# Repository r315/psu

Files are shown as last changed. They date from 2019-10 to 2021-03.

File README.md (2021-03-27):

# DPSU

Desk power supply project is intended to develop a compact desk power supply with a dummy load. The power supply can be used to power small devices and perform simple battery capacity test.

---
## Specs

### Power supply

Output: 1.3V - 20V
Output Current: 0A - 1A
Voltage adjustment steps: 100mV
Current adjustment steps: 10mA

### Battery charger

Max charge current: 1A
Battery types: 1S to 4S Li-ion

### Dummy load

Max load: 0.5A
Battery capacity test

---
## Features

* 0.96" Color TFT Screen
* Frontal USB port type A for usb power output
* 1S to 4S Li-ion battery balancer
* Optional supply voltage from internal battery
* Soft power control
* USB serial port available on rear micro usb port type B
* Digital control from tactile keys or serial

---
## Schematics

[Power board](/doc/dpsu_revA_Power_board.PDF)<br>
[Main board](/doc/dpsu_revA_Main_board.PDF)<br>
[Front board](/doc/dpsu_revA_Front_board.PDF)<br>

---
## Images

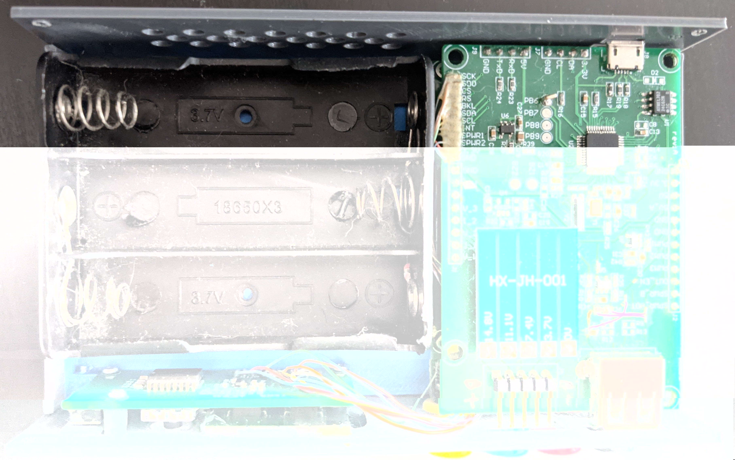
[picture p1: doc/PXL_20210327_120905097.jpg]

<div><br></div>
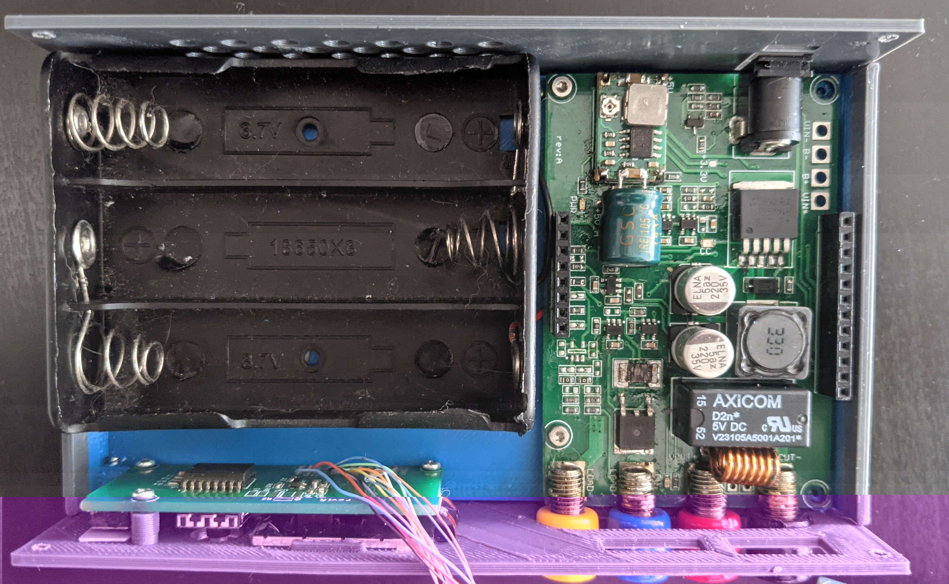
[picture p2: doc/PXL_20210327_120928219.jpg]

<div><br></div>
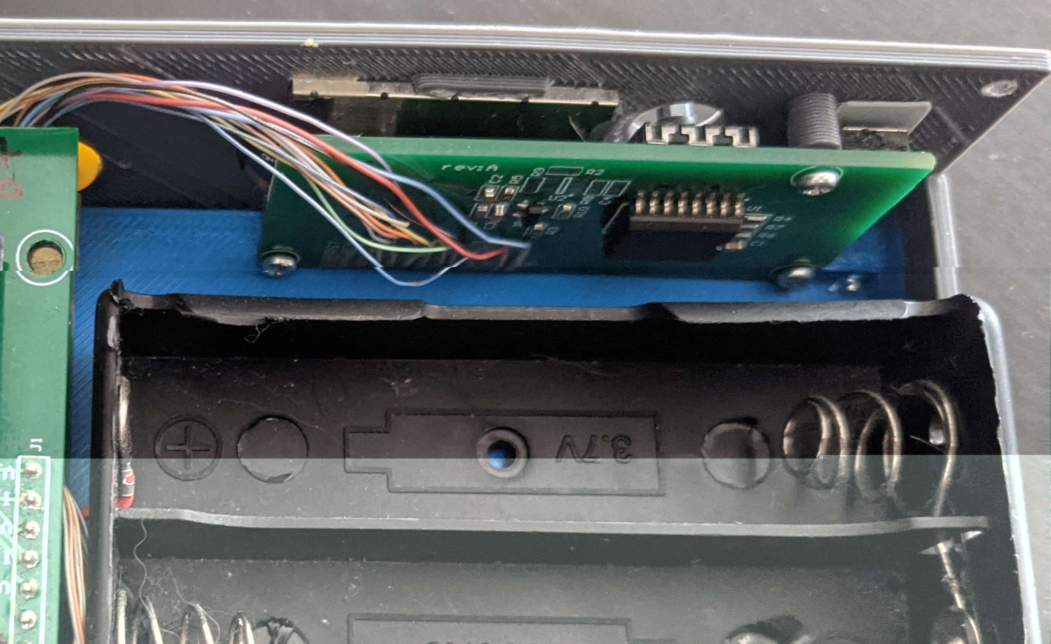
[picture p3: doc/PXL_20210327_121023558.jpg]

<div><br></div>

<div><br></div>
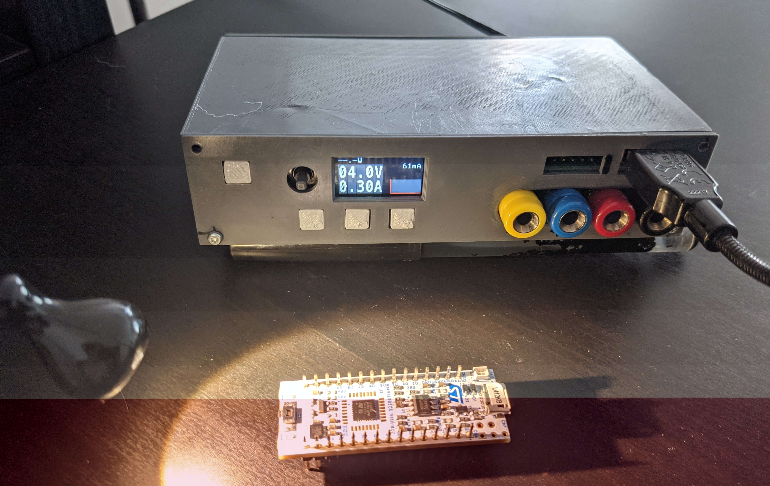
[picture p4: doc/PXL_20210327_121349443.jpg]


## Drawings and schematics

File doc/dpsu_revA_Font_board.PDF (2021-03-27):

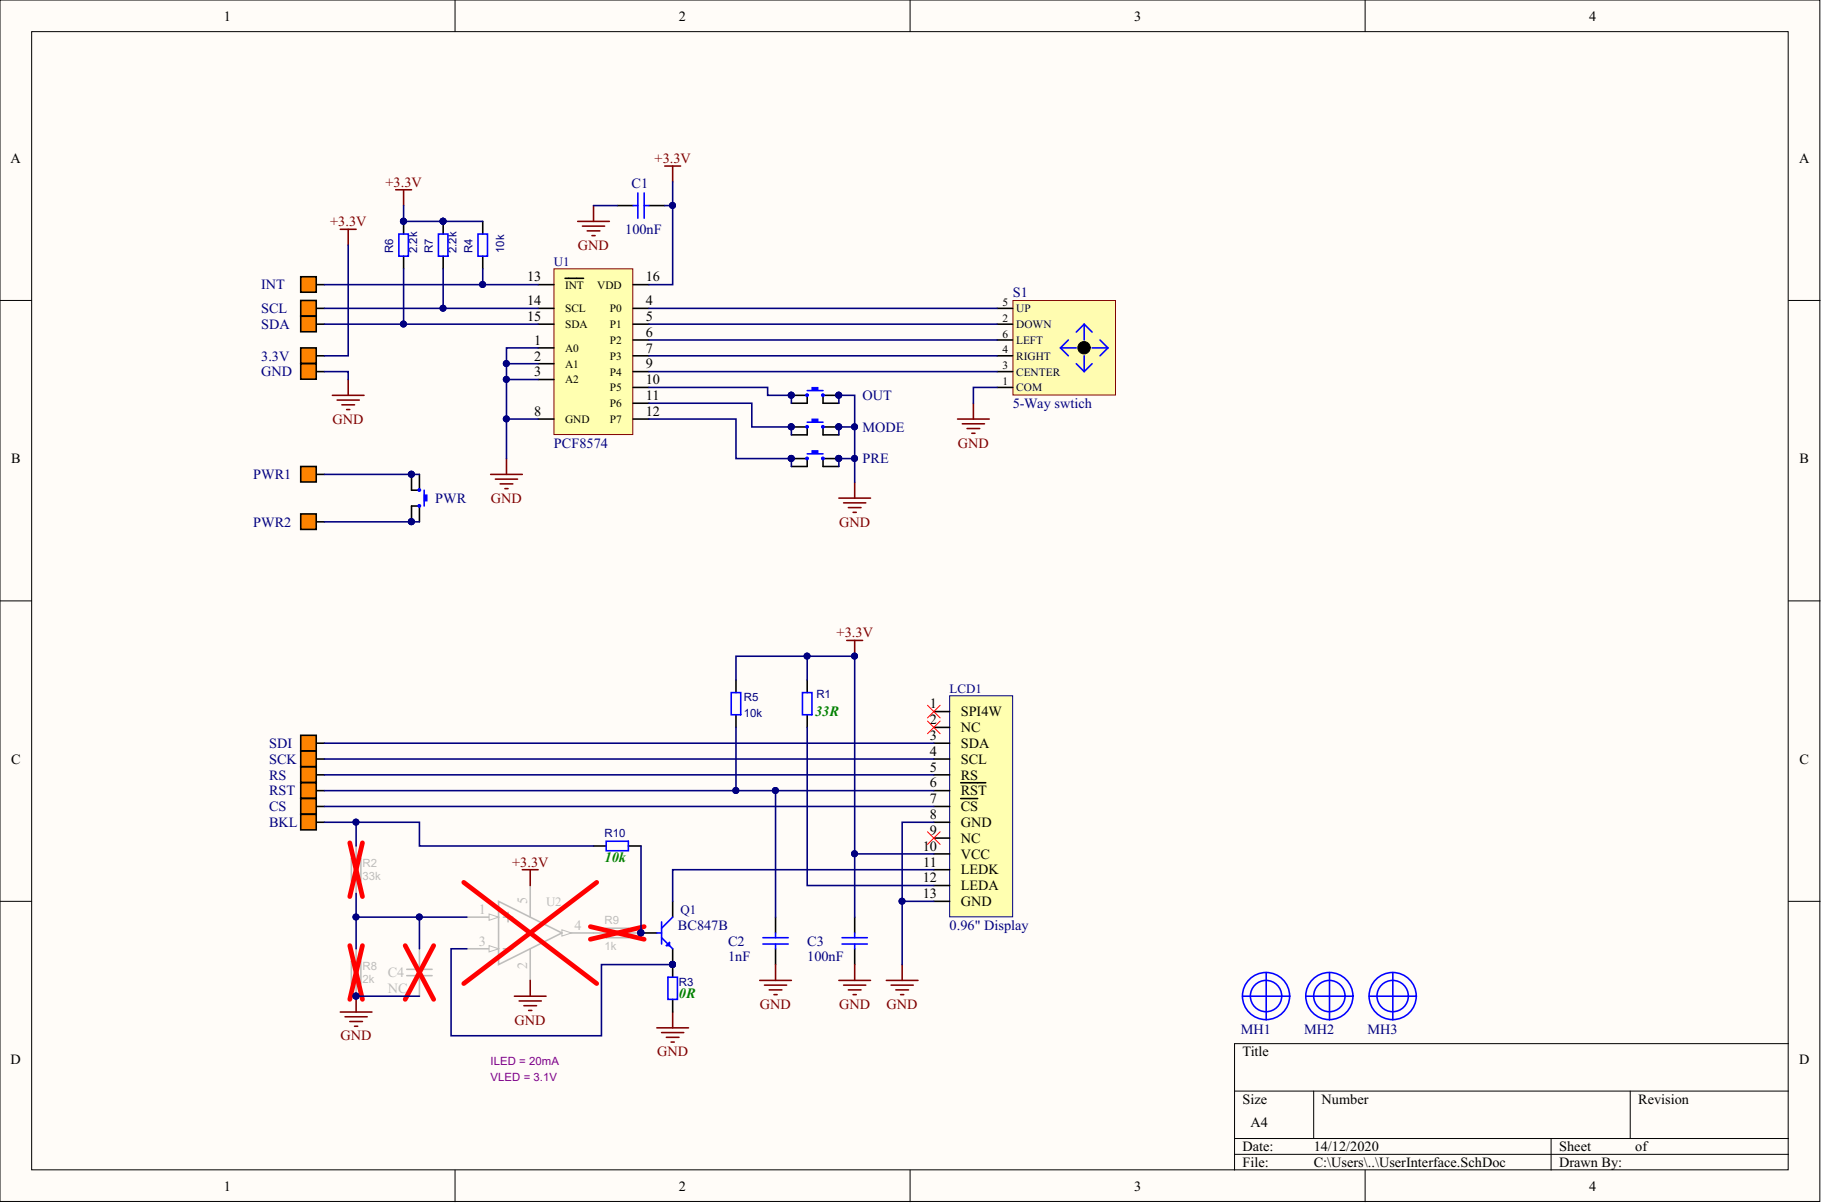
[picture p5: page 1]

SDA 3
SCL 4
RS 5
RST 6
CS 7
GND 8
NC 9

LEDK 11

GND 13

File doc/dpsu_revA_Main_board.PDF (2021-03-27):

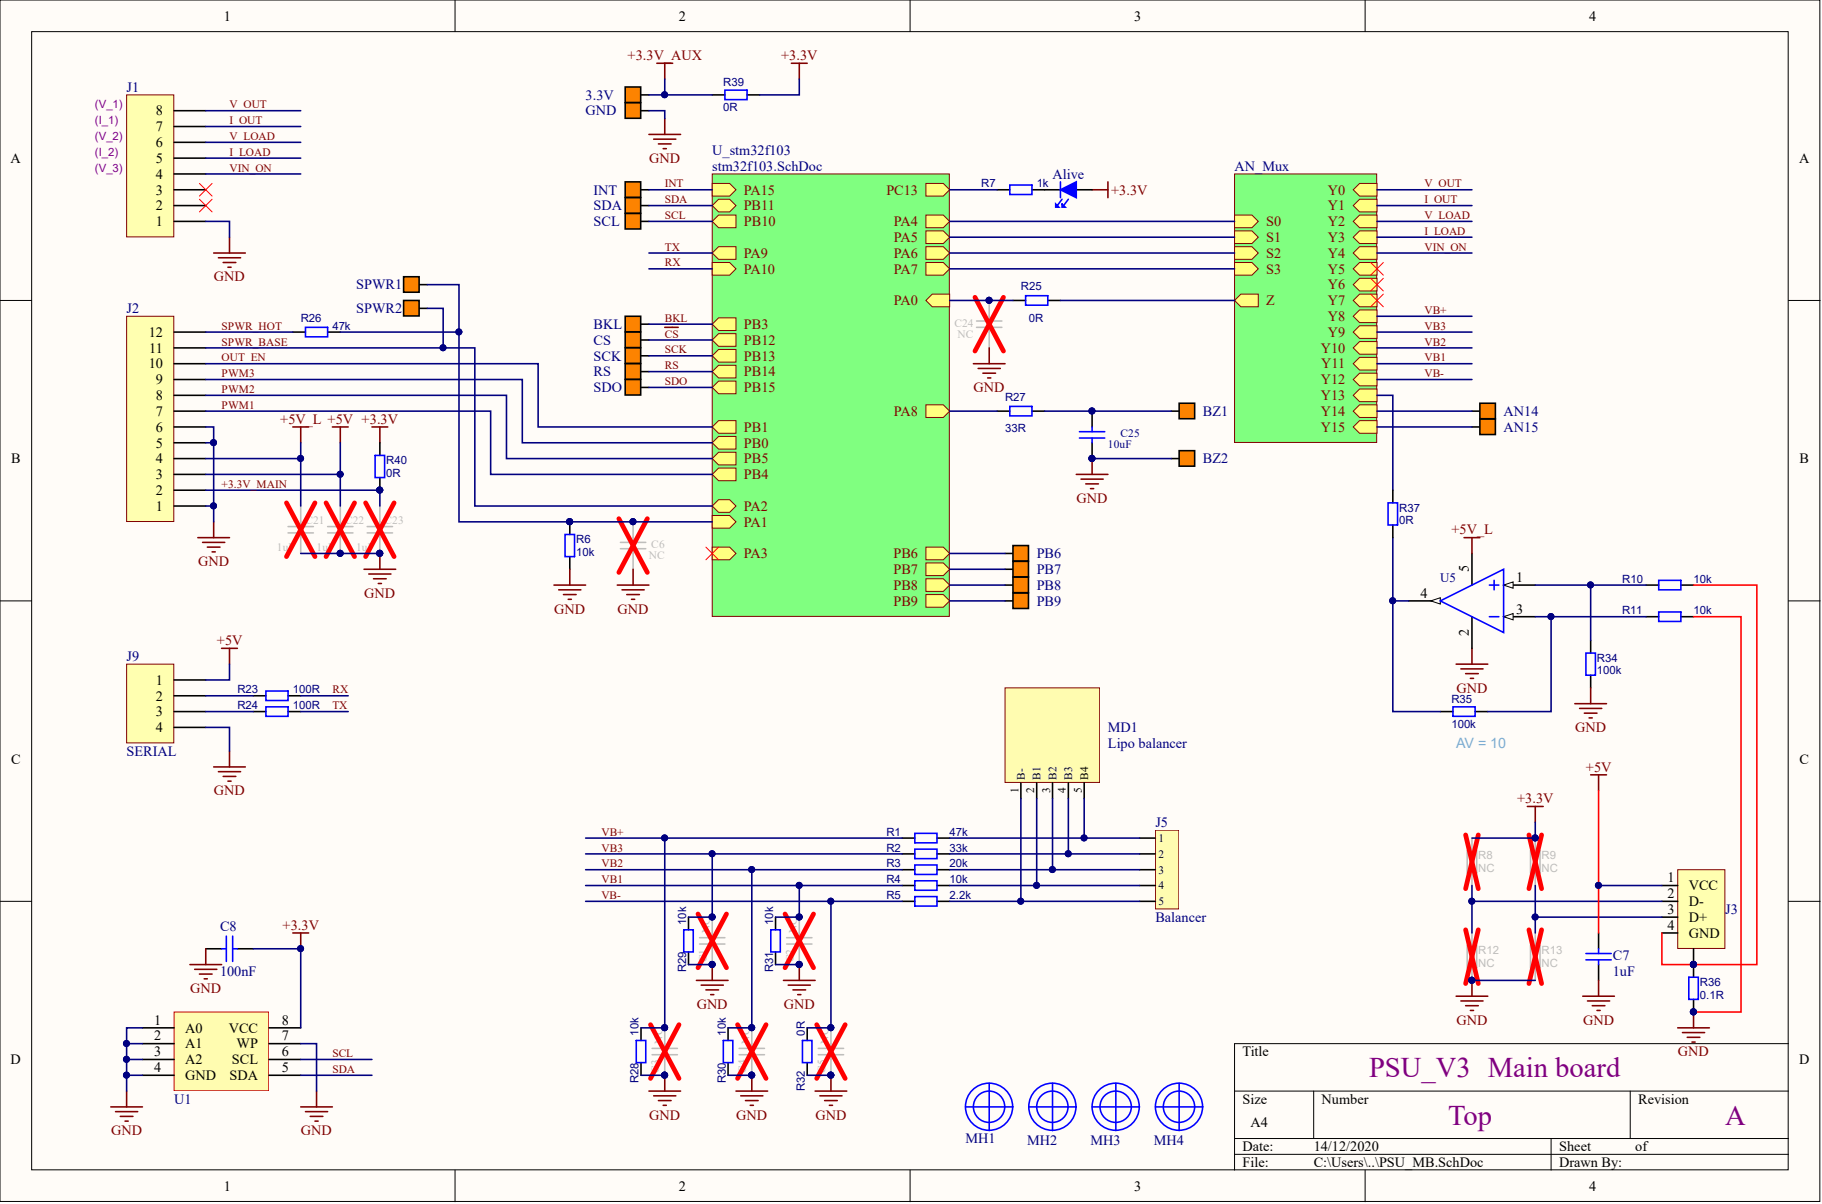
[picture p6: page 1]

OUT_EN | SCK | SCK
PWM3 | RS | RS
PWM2 | SDO | SDO

PWM1

+3.3V_MAIN

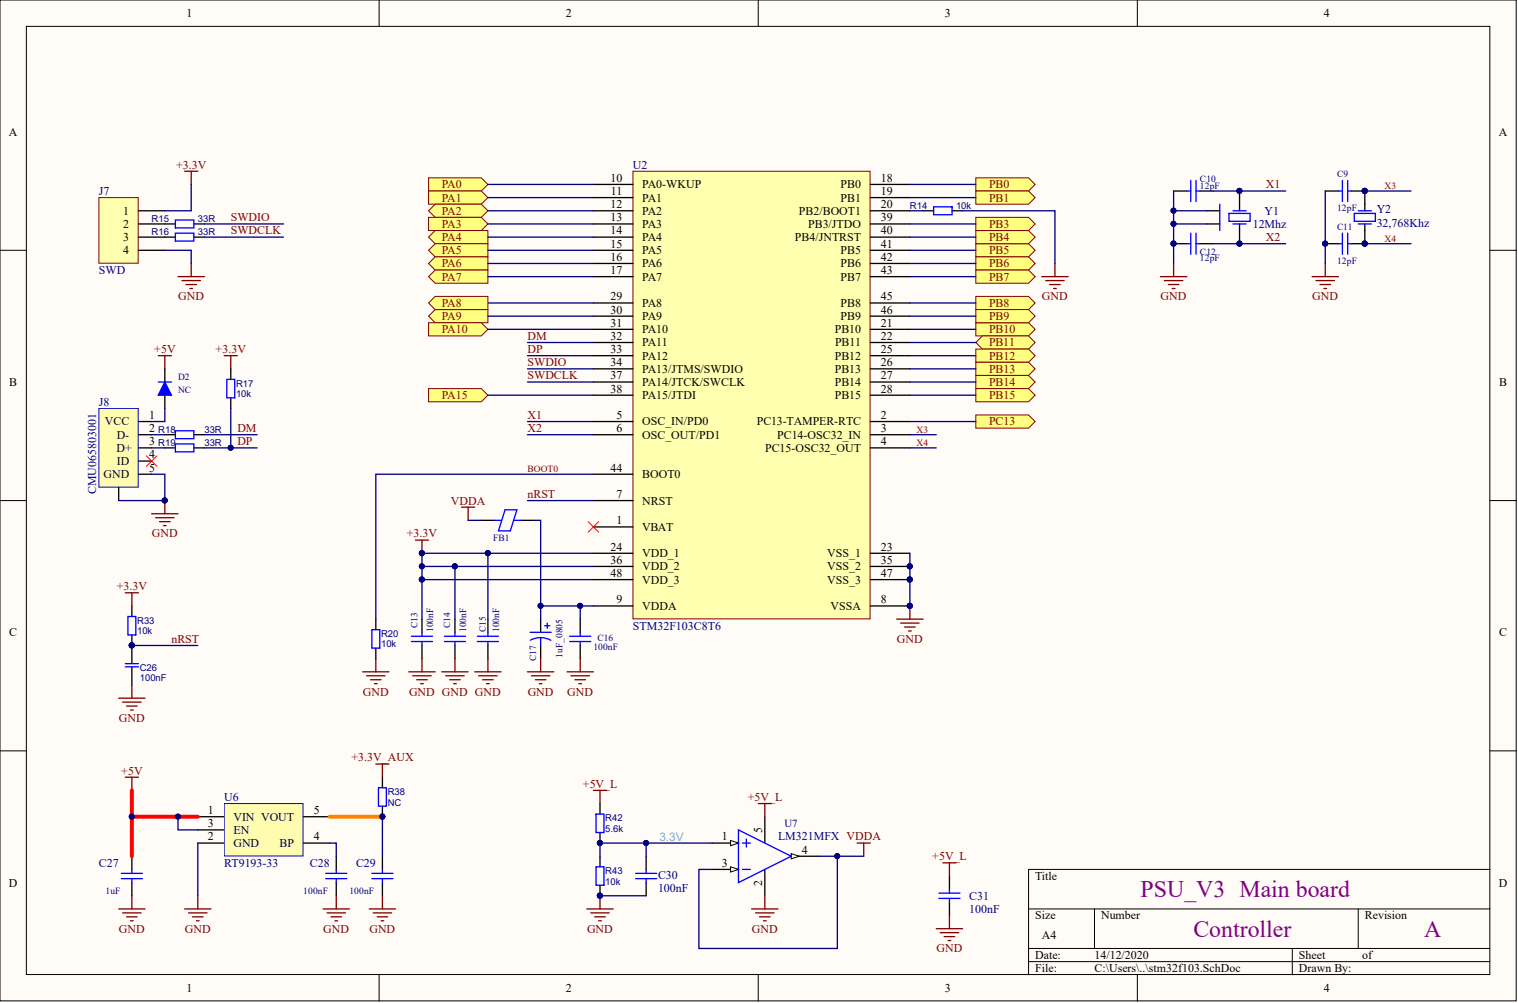
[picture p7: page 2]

VDD_2 36

VDDA 9

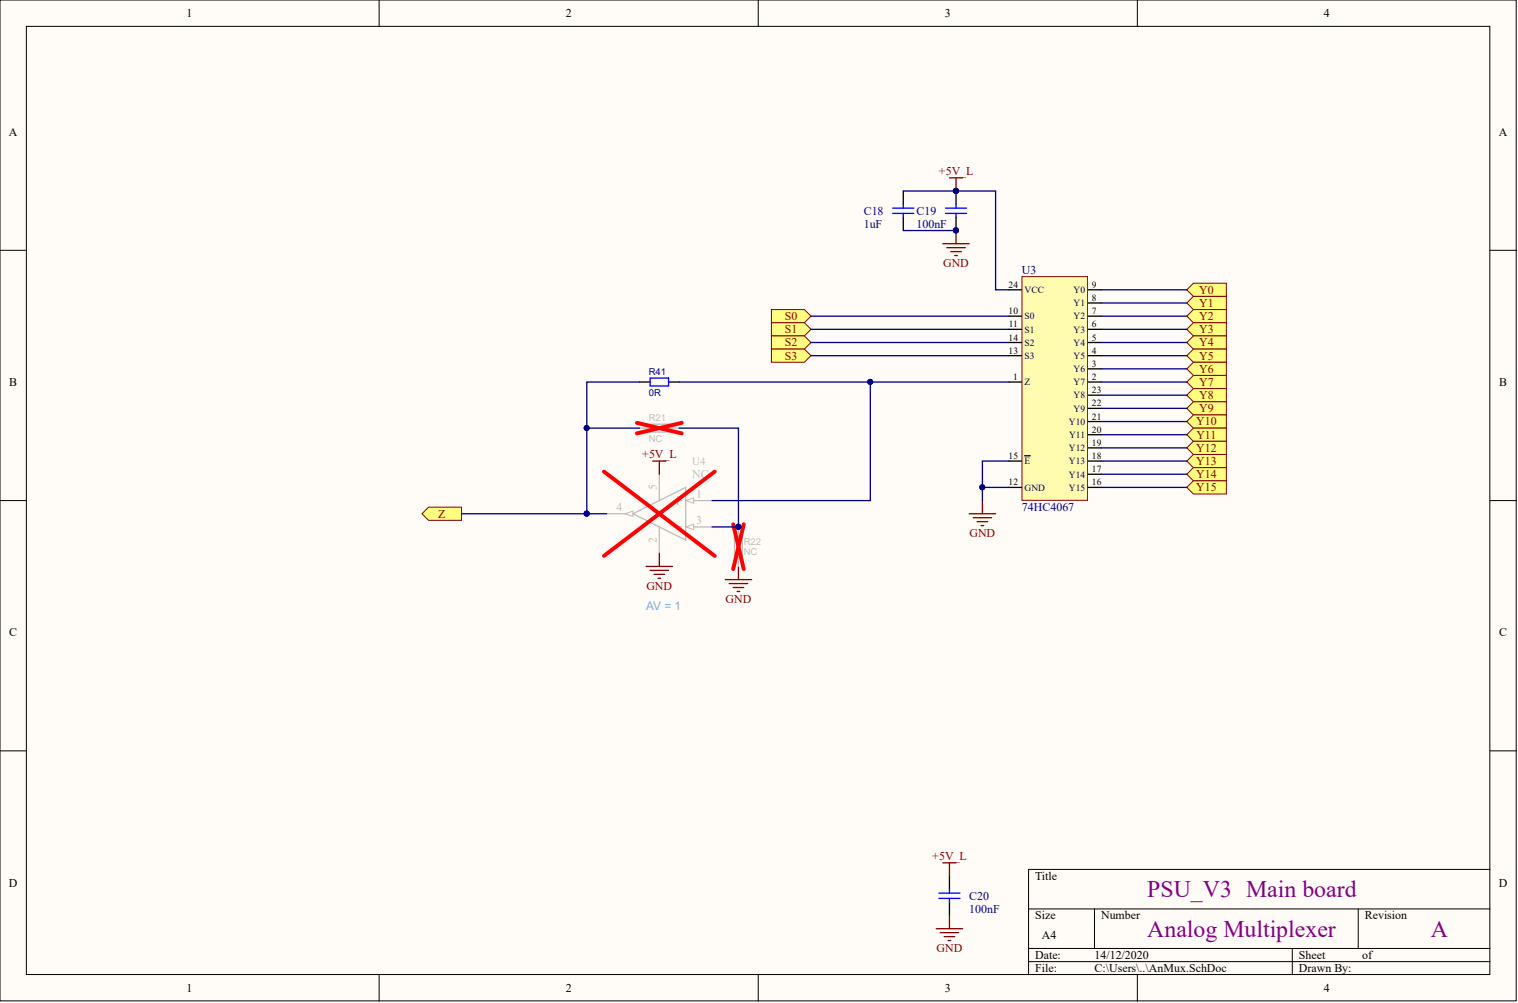
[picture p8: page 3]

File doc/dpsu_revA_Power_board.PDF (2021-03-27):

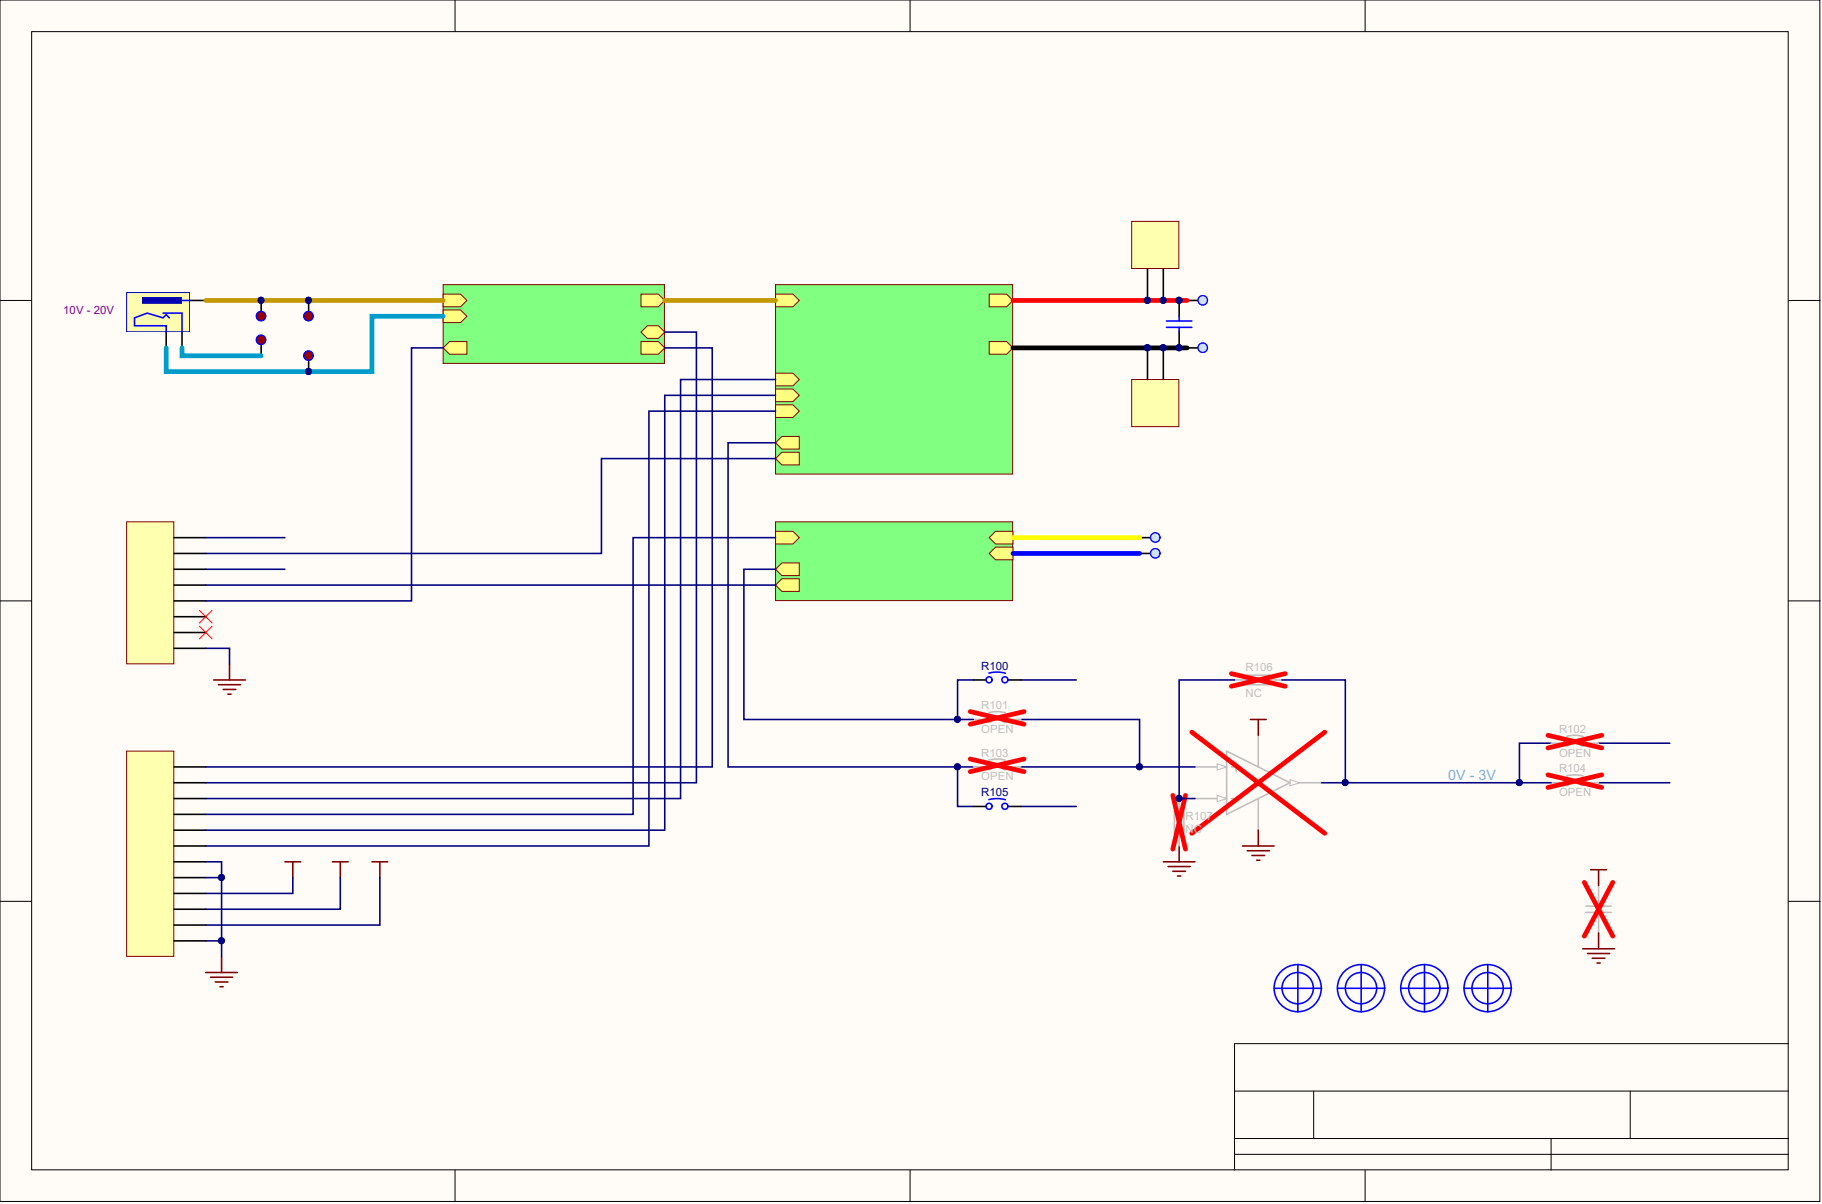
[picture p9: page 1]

V_OUT
I_OUT
V_LOAD I_LOAD

PWM_L LOAD+ LOAD-V_LOAD

I_LOAD

VIN_ON

PWM

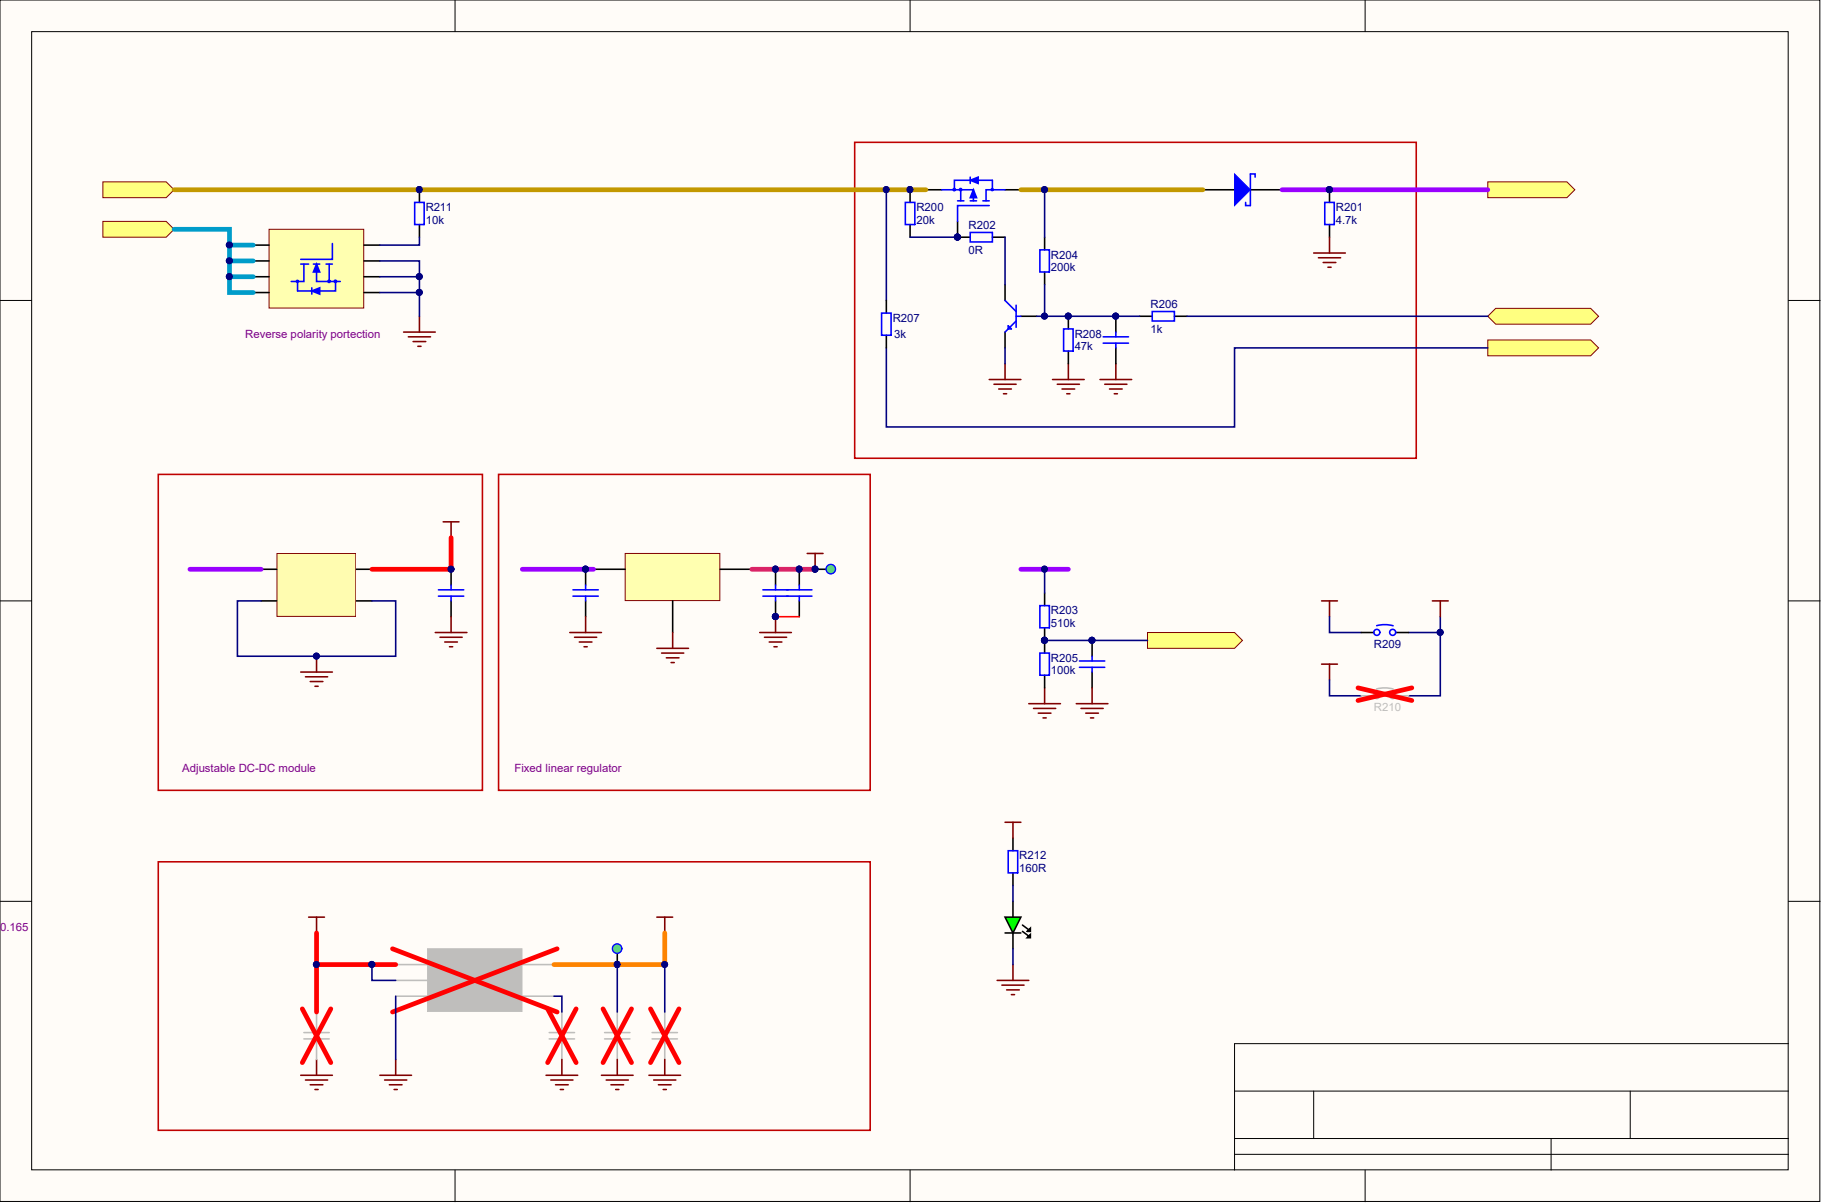
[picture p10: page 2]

Adjustable DC-DC module

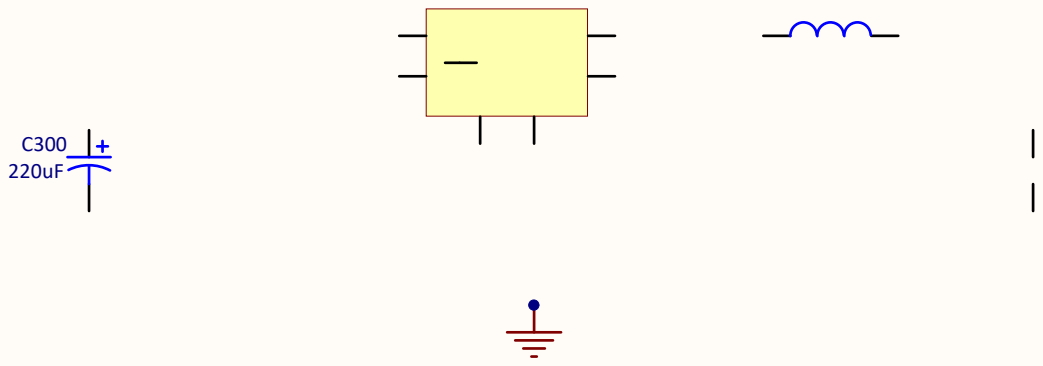
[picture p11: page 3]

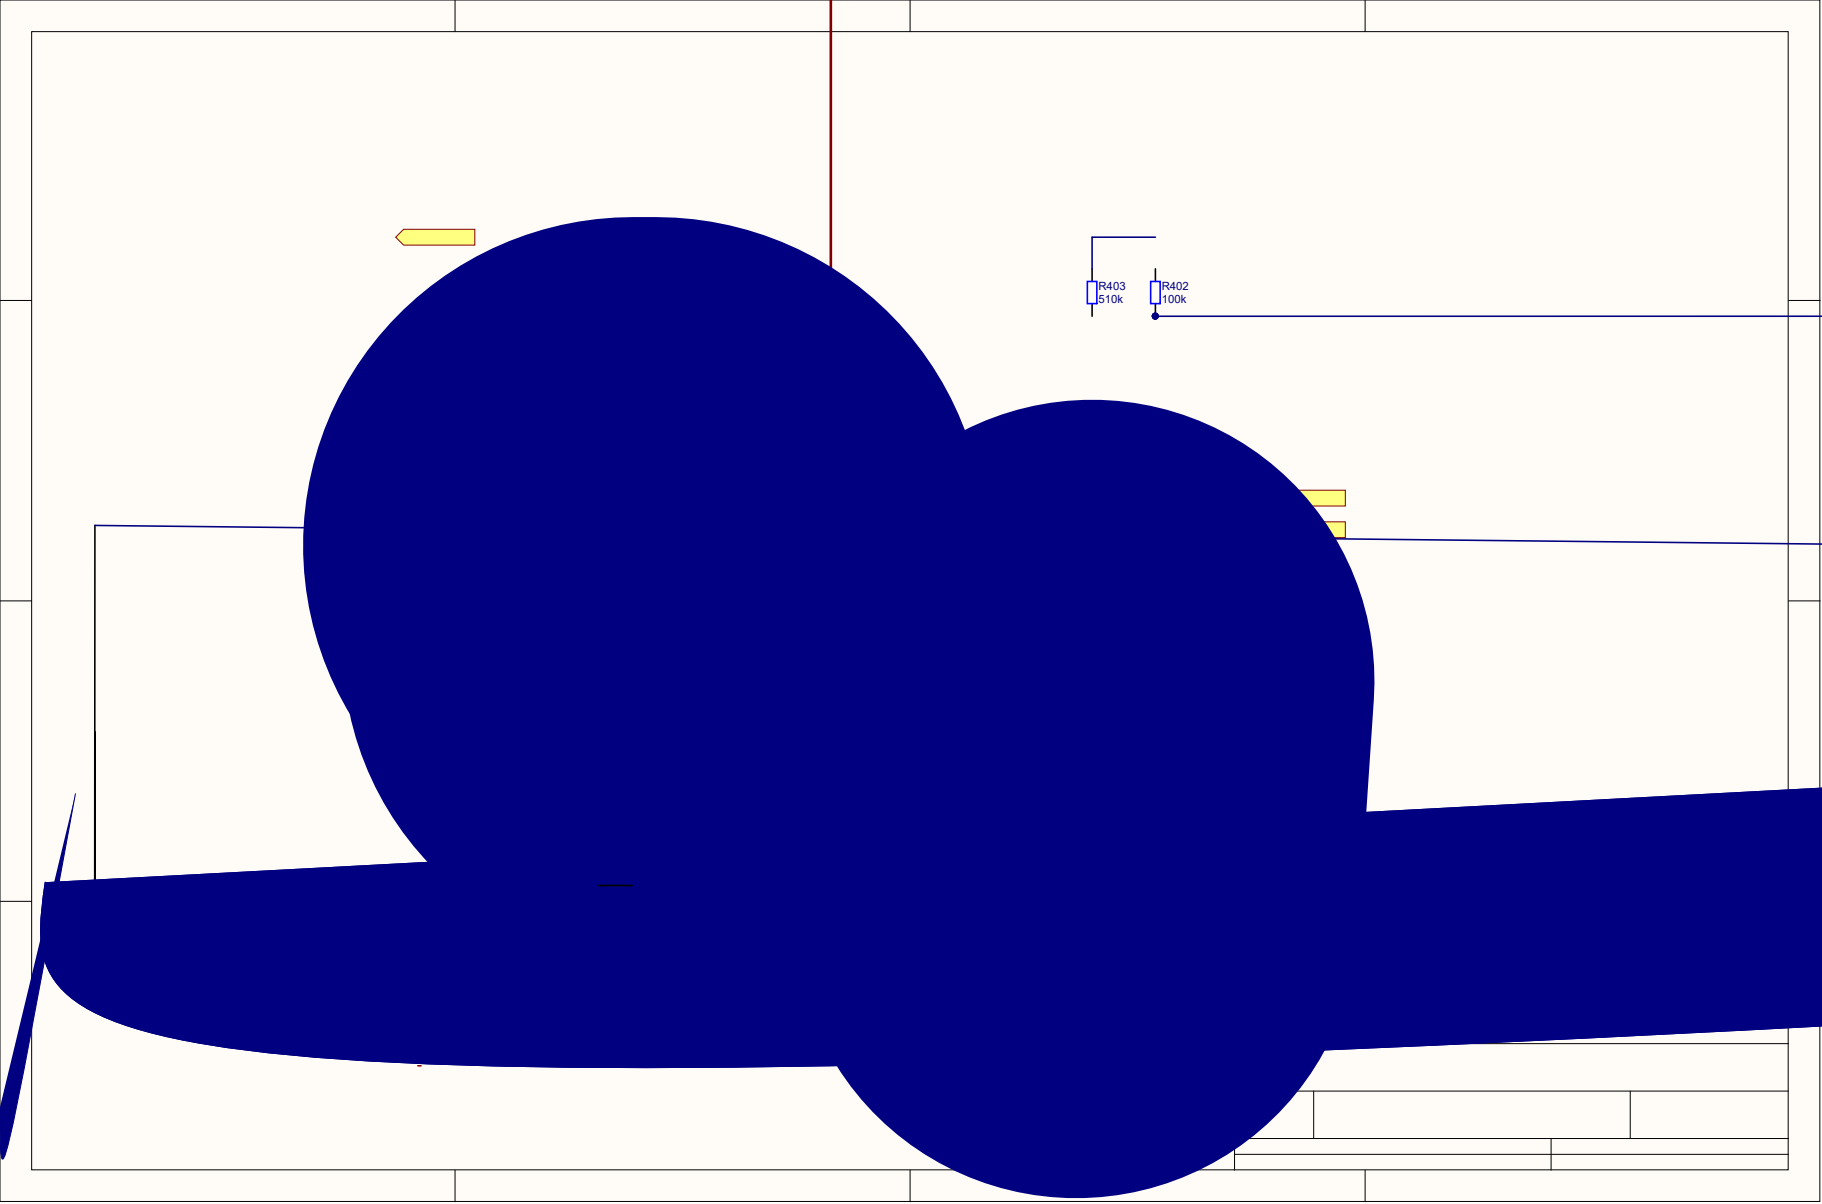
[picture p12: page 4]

I_LOAD

GND R408

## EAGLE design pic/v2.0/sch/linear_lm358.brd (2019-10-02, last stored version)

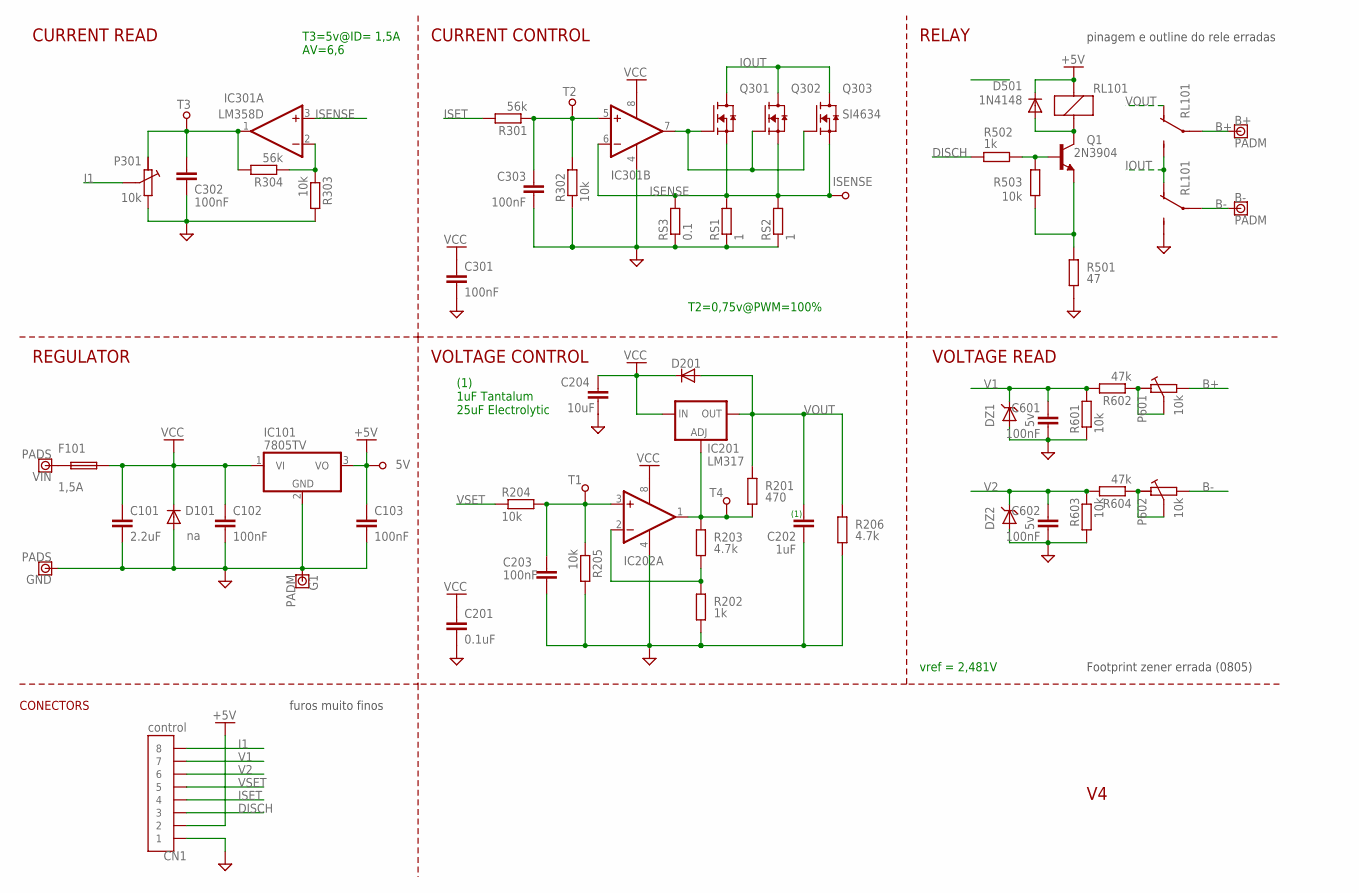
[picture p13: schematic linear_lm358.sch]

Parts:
5V: TEST_POINT; TP
B+: PADM; PAD_1M
B-: PADM; PAD_1M
C101: 2.2uF; C3225
C102, C103: 100nF; C3225
C201: 0.1uF; C0805K
C202: 1uF; C1210
C203, C301, C302, C303, C601, C602: 100nF; C0805K
C204: 10uF; C1210
CN1: control; SIL8-0.7
D101, D201: na; DO214BA
D501: 1N4148; DO214BA
DZ1, DZ2: 5v; D0805
F101: 1,5A; F1210L
G1: PADM; PAD_1M
GND: PADS; PAD_01
IC101: 7805TV; TO220V
IC201: LM317; 317TS
IC202, IC301: LM358D; SO08
ISENSE: TEST_POINT; TP
P301, P601, P602: 10k; TRIM_POT
Q1: 2N3904; SOT23
Q301, Q302: AO4468; SO-8
Q303: SI4634; SO-8
R201: 470; M0805
R202: 1k; M0805
R203, R206: 4.7k; M0805
R204, R205, R302, R303, R601, R603: 10k; M0805
R301, R304: 56k; M0805
R501: 47; R0603
R502: 1k; R0603
R503: 10k; R0603
R602, R604: 47k; M0805
RL101: RELAY_351S; 351S
RS1, RS2: 1; 0617/17
RS3: 0.1; R2512
T1, T2, T3, T4: TEST_POINT; TP
VIN: PADS; PAD_01

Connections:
+5V: 5V.1, C103.1, CN1.2, D501.C, IC101.3 (VO), RL101.C1 (1)
B+: B+.1, P601.3, RL101.P1
B-: B-.1, P602.3, RL101.P2
DISCH: CN1.3, R502.2
GND: C101.2, C102.2, C103.2, C201.2, C202.2, C203.2, C204.2, C301.2, C302.1, C303.1, C601.2, C602.2, CN1.1, D101.A, DZ1.A, DZ2.A, G1.1, GND.P, IC101.2 (GND), IC202.4 (V-), IC301.4 (V-), P301.3, R202.2, R205.2, R206.2, R302.1, R303.2, R501.1, R601.1, R603.2, RL101.NO2 (NO), RS1.1, RS2.1, RS3.1
I1: CN1.8, P301.2
IOUT: Q301.5 (D), Q301.6 (D), Q301.7 (D), Q301.8 (D), Q302.5 (D), Q302.6 (D), Q302.7 (D), Q302.8 (D), Q303.5 (D), Q303.6 (D), Q303.7 (D), Q303.8 (D), RL101.NC2 (NC), RL101.NO1 (NO)
ISENSE: IC301.3 (+IN), IC301.6 (-IN), ISENSE.1, Q301.1 (S), Q301.2 (S), Q301.3 (S), Q302.1 (S), Q302.2 (S), Q302.3 (S), Q303.1 (S), Q303.2 (S), Q303.3 (S), RS1.2, RS2.2, RS3.2
ISET: CN1.4, R301.2
unnamed: IC301.7 (OUT), Q301.4 (G), Q302.4 (G), Q303.4 (G)
unnamed: C303.2, IC301.5 (+IN), R301.1, R302.2, T2.1
unnamed: P601.1, P601.2, R602.1
unnamed: IC201.1 (ADJ), IC202.1 (OUT), R201.1, R203.1, T4.1
unnamed: Q1.2 (E), R501.2, R503.2
unnamed: C302.2, IC301.1 (OUT), P301.1, R304.2, T3.1
unnamed: Q1.1 (B), R502.1, R503.1
unnamed: D501.A, Q1.3 (C), RL101.C2 (2)
unnamed: IC301.2 (-IN), R303.1, R304.1
unnamed: IC202.2 (-IN), R202.1, R203.2
unnamed: F101.1, VIN.P
unnamed: P602.1, P602.2, R604.1
unnamed: C203.1, IC202.3 (+IN), R204.2, R205.1, T1.1
V1: C601.1, CN1.7, DZ1.K (C), R601.2, R602.2
V2: C602.1, CN1.6, DZ2.K (C), R603.1, R604.2
VCC: C101.1, C102.1, C201.1, C204.1, C301.1, D101.C, D201.C, F101.2, IC101.1 (VI), IC201.3 (IN), IC202.8 (V+), IC301.8 (V+)
VOUT: C202.1, D201.A, IC201.2 (OUT), R201.2, R206.1, RL101.NC1 (NC)
VSET: CN1.5, R204.1

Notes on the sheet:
(1) 1uF Tantalum 25uF Electrolytic
RELAY
CURRENT CONTROL
VOLTAGE CONTROL
CURRENT READ
VOLTAGE READ
(1)
REGULATOR
CONECTORS
pinagem e outline do rele erradas
furos muito finos
vref = 2,481V
T3=5v@ID= 1,5A AV=6,6
Footprint zener errada (0805)
T2=0,75v@PWM=100%

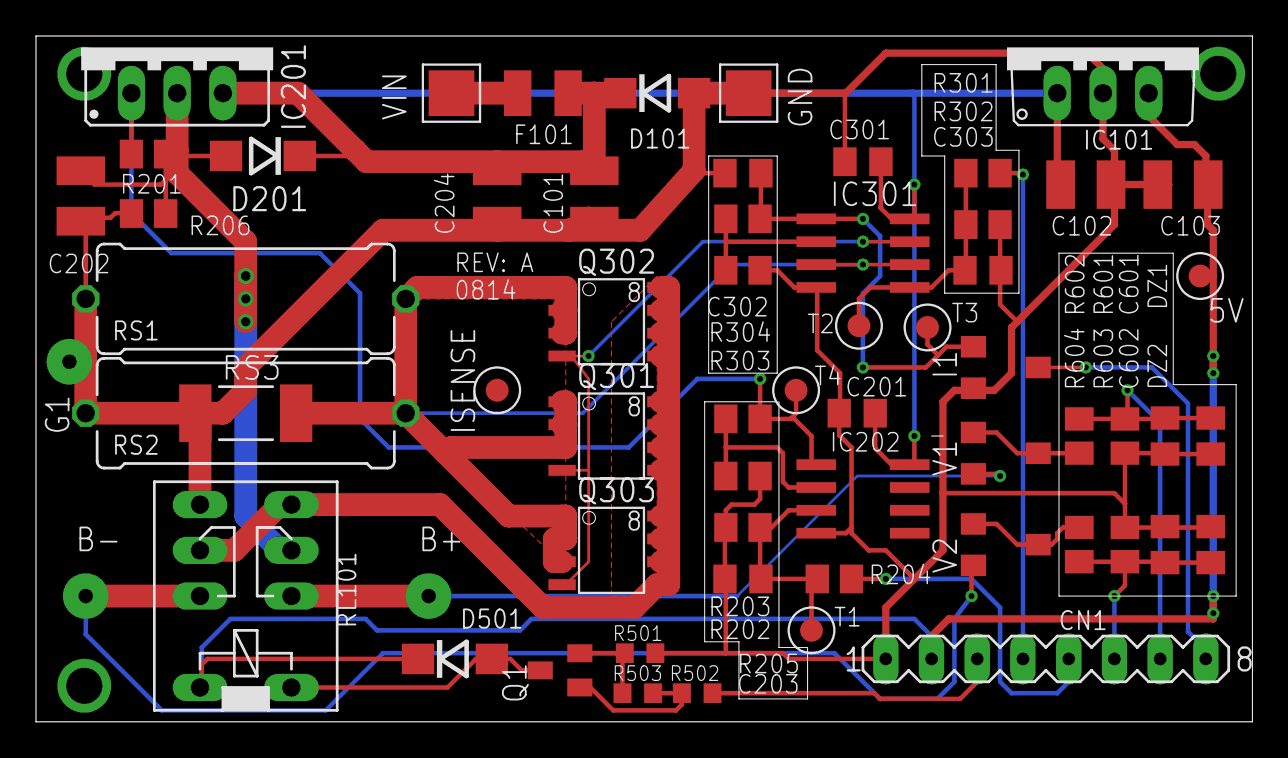
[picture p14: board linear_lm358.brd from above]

Board: 2 copper layers, 67.6 x 38.1 mm, 62 parts (0 on the bottom side), 27 nets.

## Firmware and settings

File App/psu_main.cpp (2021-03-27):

#include <console.h>

#include "FreeRTOS.h"
#include "task.h"

#include "psu.h"
#if defined(ENABLE_CLI)
#include "misc.h"
#include "cmdhelp.h"
#include "cmdadc.h"
#include "cmdpwm.h"
#include "cmddfu.h"
#include "cmdset.h"
#include "cmdstatus.h"
#include "cmdeeprom.h"
#endif

static psu_t psu;
#if defined(ENABLE_CLI)
static Console console;
static CmdHelp help;
static CmdAdc adc1;
static CmdPwm pwm;
static CmdPwr pwr;
static CmdIo io;
static CmdSet set;
static CmdReset reset;
#ifdef ENABLE_EEPROM
static CmdEeprom eeprom;
#endif
#ifdef ENABLE_DFU
static CmdDfu dfu;
#endif
static CmdStatus status;

static ConsoleCommand *commands[] = {
    &help,
    &adc1,
    &pwm,
    &pwr,
    &io,
    &set,
#ifdef ENABLE_DFU
    &dfu,
#endif
    &reset,
    &status,
#ifdef ENABLE_EEPROM
    &eeprom,
#endif
    NULL
};
#endif

#if defined(ENABLE_UI)
#include "bui.h"
#include "model_psu.h"
#include "presenter_psu.h"
#include "presenter_preset.h"
#include "presenter_charger.h"
#include "presenter_load.h"

static ModelPsu model_psu;
#endif

volatile uint32_t g_mgr_eoc_count = 0;

const pwmcal_t default_pwm_calibration[] = {
    {490, (1<<PWM_RESOLUTION), 1024},   // pwm1 (VOUT) calibration <min, max, start>
    {0, (1<<PWM_RESOLUTION), 100},      // pwm2 (IOUT) calibration
    {0, (1<<PWM_RESOLUTION), 0},        // pwm3 (ILOAD) calibration MUST be 0
};

const preset_t default_preset[] = {
    {1800, 200},   // <mv, ma>
    {2500, 200},
    {3300, 500},
    {4200, 300},
    {5000, 200},
    {9600, 100}
};

const float default_an_channel_gain[] = {
    6.13f,  // V1 = 1/(R300/(R300+R301))
    0.9f,  // I1 = VRS / AV(10) / RS(0.1) <=> VRS
    6.1f,  // V2 = 1/(R402/(R402+R403))
    1.0f,  // I2
    6.1f,  // V3 = 1/(R205/(R205+R203))
    1.0f,
    1.0f,
    1.0f,
    5.77f,  // MUX8  B+
    4.39f,  // MUX9  VB3
    3.08f,  // MUX10 VB2
    2.05f,  // MUX11 VB1
    1.0f,  // MUX12 B-
    1.0f,  // MUX13 IUSB
    1.0f,
    1.0f
};

/**
 * PSU
 * */

/**
 * @brief Callback from adc manager
 * 
 * \param data : pointer to raw adc data. The number of results is equal 
 * to the size of the conversion sequence, and only valid until the next call tp ADCMGR_Start()
 *
 * */
extern "C" void psu_adc_cb(uint16_t *data){
    if(GET_AD_FLAG == 0){
        psu.adc_data = data;
        g_mgr_eoc_count++;
        SET_AD_FLAG;
    }
}

static void mapAndSetPwm(float x, float in_max, float in_min, uint8_t ch){
    uint16_t pwm_value = (x - in_min) * (psu.pwm_cal[ch].max - psu.pwm_cal[ch].min) / (in_max - in_min) + psu.pwm_cal[ch].min;
    PWM_Set(ch, pwm_value);
    DBG_PRINT("Set PWM%d %u\n",ch, pwm_value);
}

#if defined(ENABLE_EEPROM)
static uint8_t app_calcCksum(uint8_t *src, uint16_t len){
    uint8_t sum = 0;

    while(len--){
        sum += *src++;
    }

    return 256 - sum;
}
#endif

/**
 * PSU public control functions
 * */
void psu_poweroff(void){
    
    psu_setOutputEnable(FALSE);
    psu_setLoadCurrent(0);
#if defined(ENABLE_UI)
    LCD_Bkl(OFF);
#endif
    vTaskDelay(pdMS_TO_TICKS(POWER_OFF_DELAY));
    SOFT_POWER_OFF;
}

void psu_setOutputEnable(uint8_t en){
    PSU_OE_SET(en);
}

void app_setOutputEnable(uint8_t en){
    if(en){
        SET_OE_FLAG;
    }else{
        CLR_OE_FLAG;
    }
    psu_setOutputEnable(en);
}

uint8_t app_toggleOutputEnable(void){
    app_setOutputEnable(!GET_OE_FLAG);
    return GET_OE_FLAG;
}

void app_setLoadEnable(uint8_t en){
    if(en){
        SET_LD_FLAG;
    }else{
        CLR_LD_FLAG;
    }
}

/**
 * @brief Get channel voltage
 * 
 * \param channel : Channel 
 * \return : voltage in mv
 * */
uint32_t psu_getChannelVoltage(uint8_t channel){
    return psu.adc_data[channel] * ADC_GetResolution() * psu.an_channel_gain[channel];
}

/**
 * @brief Get cell voltage at balancer terminals
 * \param c : cell number [0,3], counting from gnd
 * \return : cell voltage in mV
 * */
uint32_t psu_getCellVoltage(uint8_t c){
    return psu_getChannelVoltage(VB0_MUX_CH - (c + 1));
}

uint32_t psu_getOutputVoltage(void){
    return psu_getChannelVoltage(VOUT_MUX_CH);
}

void psu_setOutputVoltage(uint32_t mv){    
    mapAndSetPwm(mv, MIN_VOLTAGE, MAX_VOLTAGE, PWM_CH_VOLTAGE);
}

uint32_t psu_getOutputCurrent(void){
    uint32_t i = psu_getChannelVoltage(IOUT_MUX_CH);
    // Filter dead band due not using rail to rail op amps
    return (i < 10) ? 0 : i;
}

void psu_setOutputCurrent(uint32_t ma){
    mapAndSetPwm(ma, MAX_CURRENT, MIN_CURRENT, PWM_CH_CURRENT);
}

uint32_t psu_getLoadCurrent(void){
    return psu_getChannelVoltage(ILOAD_MUX_CH);;
}

void psu_setLoadCurrent(uint32_t ma){
    mapAndSetPwm(ma, MAX_ILOAD, MIN_ILOAD, PWM_CH_LOAD);
}

uint32_t psu_getInputVoltage(void){
    return psu_getChannelVoltage(VIN_MUX_CH);
}

uint32_t psu_getLoadVoltage(void){
    return psu_getChannelVoltage(VLOAD_MUX_CH);
}

uint32_t psu_getUsbCurrent(void){
    uint32_t i = psu_getChannelVoltage(IUSB_MUX_CH);
    // Filter dead band due not using rail to rail op amps
    return (i < 10) ? 0 : i;
}

float psu_getChannelGain(uint8_t ch){
    if(ch >= AN_MUX_NUM_CH){
        return 0;
    }
    return psu.an_channel_gain[ch];
}

void psu_setChannelGain(uint8_t ch, float g){
    if(ch < AN_MUX_NUM_CH){
        psu.an_channel_gain[ch] = g;        
    }
}

void psu_setPwmChannelCalibration(uint8_t ch, uint16_t min, uint16_t max){
    psu.pwm_cal[ch].min = min;
    psu.pwm_cal[ch].max = max;
}
pwmcal_t psu_getPwmChannelCalibration(uint8_t ch){
    return psu.pwm_cal[ch];
}

/**
 * Application api
 * */
void app_processPowerButton(void){
    static uint16_t pwr_off_counter = POWER_OFF_COUNT;

    //DBG_PRINT("ADC2 :%x\n", ADC2_Read(ADC_PWR_SW_CH));

    if(GET_PWR_BTN){
        if(--pwr_off_counter == 0){
            DBG_PRINT("Powering off...\n");
            app_saveState();
            psu_poweroff();
    }
    }else{
        pwr_off_counter = POWER_OFF_COUNT;
    }
}

uint8_t app_isLoadEnabled(void){
    return GET_LD_FLAG;
}

uint8_t app_isAdcDone(void){
    return GET_AD_FLAG;
}

uint8_t app_isOutputEnabled(void){
    return  GET_OE_FLAG;
}

preset_t *app_getPresetList(void){
    return psu.preset_list;
}

uint8_t app_getPresetIdx(void){
    return psu.preset_idx;
}

void app_setPresetIdx(uint8_t idx){
    psu.preset_idx = idx;
}

void app_applyPreset(preset_t *pre){
    psu_setOutputVoltage(pre->v);
    psu_setOutputCurrent(pre->i);
}

void app_applyPresetByIdx(uint8_t idx){
    app_applyPreset(&psu.preset_list[idx]);
}

/**
 * @brief Load default values in to EEPROM
 * */
void app_defaultState(void){
    memcpy(psu.pwm_cal, default_pwm_calibration, sizeof(default_pwm_calibration));
    memcpy(psu.preset_list, default_preset, sizeof(default_preset));
    memcpy(psu.an_channel_gain, default_an_channel_gain, sizeof(default_an_channel_gain));
    psu.preset_idx = 0;
    psu.flags = 0;
}

/**
 * @brief
 * 
 * */
uint8_t app_restoreState(void){
#ifdef ENABLE_EEPROM
    uint16_t size = (uint8_t*)&psu.cksum - (uint8_t*)&psu;

    EEPROM_Read(EEPROM_APP_OFFSET, (uint8_t*)&psu, size + 1);
    
    uint8_t cksum = app_calcCksum((uint8_t*)&psu, size);
    if( psu.cksum != cksum){
        DBG_PRINT("Invalid data on EEPROM, using default values!\n");
        app_defaultState();
        CLR_EEPROM_FLAG;
        return 0;
    }
    SET_EEPROM_FLAG;
#else
    app_defaultState();
#endif
    return 1;
}
/**
 * @brief
 * */
uint8_t app_saveState(void){
#ifdef ENABLE_EEPROM
    // Calculate cksum for current values
    uint16_t size = (uint8_t*)&psu.cksum - (uint8_t*)&psu;
    psu.cksum = app_calcCksum((uint8_t*)&psu, size);
    // Read cksum from eeprom and compare with previous calculated cksum
    uint8_t cksum;
    EEPROM_Read(EEPROM_APP_OFFSET + size, (uint8_t*)&cksum, 1);
    DBG_PRINT("EEPROM cksum: %2X, settings cksum: %2X\n", cksum, psu.cksum);
    if(cksum == psu.cksum){
        // No changes made on settings
        return 1;
    }

    DBG_PRINT("Writting %u bytes to EEPROM\n", size + 1);
    if(!EEPROM_Write(EEPROM_APP_OFFSET, (uint8_t*)&psu, size + 1)){
        return 0;
    }
    DBG_PRINT("done\n");
#endif
    return 1;
}


/**
 * @brief Task to handle user interface
 * */
#if defined(ENABLE_UI)
void tskBui(void *ptr){
    static TickType_t xLastWakeTime;

    BUIPresenter *presenter_psu = new PresenterPsu();
    BUIPresenter *presenter_preset = new PresenterPreset();
    BUIPresenter *presenter_charger = new PresenterCharger();
    BUIPresenter *presenter_load = new PresenterLoad();
    
    DRAW_FillRect(0, 0, LCD_W, LCD_H, BLACK);    
    char *text = (char*)bui_malloc(sizeof(PSU_VERSION));
    xsprintf(text, "%s", PSU_VERSION);
    DRAW_Text(100,70,text, &defaultFont, (const uint16_t[]){BLACK, GREEN});    
    bui_free(text);
    // Wait for lcd clear to end
    vTaskDelay(100);
    LCD_Bkl(TRUE);
    vTaskDelay(1000);

    BUI bui(model_psu);   
    
    bui.addPresenter(presenter_psu);
    bui.addPresenter(presenter_preset);
    bui.addPresenter(presenter_charger);
    bui.addPresenter(presenter_load);

    while(1){
        bui.handler(NULL);
        vTaskDelayUntil( &xLastWakeTime, pdMS_TO_TICKS(UPDATE_INTERVAL));
    }
}
#endif
/**
 * @brief Main task
 * */
void tskPsu(void *ptr){
static TickType_t xLastWakeTime;
uint8_t count = 0;   

    ADCMGR_Start();
#if defined(ENABLE_UI)
    model_psu.init();
#endif
    while(1){
        //DBG_PIN_LOW;        
        app_processPowerButton();
        
        if(GET_AD_FLAG){
            #if defined(ENABLE_UI)
            model_psu.update();
            #endif
            CLR_AD_FLAG;
            ADCMGR_Start();
        }

        if(((++count)&0x0f) == 0){
            LED_ON;
        }else{
            LED_OFF;
        }
        
        #ifndef ENABLE_DEBUG
        reloadWatchDog();
        #endif
        //DBG_PIN_HIGH;
        vTaskDelayUntil( &xLastWakeTime, pdMS_TO_TICKS(UPDATE_INTERVAL));
    }
}

#if defined(ENABLE_CLI)

#if !(defined(ENABLE_USB_CDC) || defined(ENABLE_UART))
#error "NO SERIAL IO DEFINED"
#endif
/**
 * @brief Task to handle serial commands
 * */
void tskCmdLine(void *ptr){
    
    stdout_t *stdio_port = (stdout_t*)ptr;

    stdio_port->init();

    #ifdef ENABLE_DEBUG
    dbg_init(SERIAL_IO);
    #endif

    console.init(stdio_port, CONSOLE_PROMPT);
    console.registerCommandList(commands);

    // wait for usb to start if connected
    //vTaskDelay(pdMS_TO_TICKS(500));

    console.cls();

    console.print("PSU v%s\n", PSU_VERSION);
    console.print("FreeRTOS %s\n", tskKERNEL_VERSION_NUMBER);
    console.print("Free mem: %u bytes\n", xPortGetFreeHeapSize());
    console.print("\n");

    while(1){
        console.process();
    }
}
#endif

/**
 * @brief private helper to start task
 * */
static void startTask(void(*task)(void*), const char *name, void *args, uint32_t stack, int priority){
    if(xTaskCreate( task, name, stack, args, priority, NULL ) != pdPASS){
        DBG_PRINT("FAIL: to start task %s\n", name);    
    }
}

extern "C" void app_setup(void){  
    BOARD_Init();  

    app_setOutputEnable(FALSE);

#if defined(ENABLE_UI)
    EXPANDER_Init();
    LCD_Init();
    LCD_Rotation(LCD_LANDSCAPE);
#endif

#ifdef ENABLE_EEPROM
    EEPROM_Init();
#endif
    app_restoreState();

    PWM_Init(psu.pwm_cal[0].init, psu.pwm_cal[1].init, psu.pwm_cal[2].init);

    ADCMGR_Init();

    ADCMGR_SetSequence(NULL, 0 , psu_adc_cb);

    // Configure watchdog
    #ifndef ENABLE_DEBUG
    enableWatchDog(WATCHDOG_TIME);
    #endif

    startTask(tskPsu, "PSU", NULL, configMINIMAL_STACK_SIZE, PRIORITY_LOW + 1);
#if defined(ENABLE_CLI)   
    startTask(tskCmdLine, "CLI", SERIAL_IO, configMINIMAL_STACK_SIZE * 2, PRIORITY_LOW);
#endif
#if defined(ENABLE_UI)
    startTask(tskBui, "BUI", NULL, configMINIMAL_STACK_SIZE * 8, PRIORITY_LOW);
#endif
}

extern "C" void vApplicationMallocFailedHook( void ){
    DBG_PRINT("Memory allocation fail\n");
}

void *operator new(size_t size){
    DBG_PRINT("Allocating: %u bytes\n", size);
    return pvPortMalloc(size);
}

void operator delete(void *ptr){
    vPortFree(ptr);
    DBG_PRINT("Free mem: %u bytes\n", xPortGetFreeHeapSize());
}

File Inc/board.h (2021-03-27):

#ifndef _board_h_
#define _board_h_

#ifdef __cplusplus
extern "C" {
#endif

#include <button.h>
#include <stdout.h>
#include "stm32f1xx.h"
#include "pcf8574.h"
#include "lcd.h"
#include "st7735.h"
#include "adcmgr.h"
#include "pinName.h"
#include "dbg.h"
#include "eeprom.h"


/**
 * Button 
 * */
#define BUTTON_UP       (1<<2)
#define BUTTON_DOWN     (1<<3)
#define BUTTON_LEFT  	(1<<1)
#define BUTTON_RIGHT 	(1<<0)
#define BUTTON_SET  	(1<<4)
#define BUTTON_MODE     (1<<6)
#define BUTTON_OUT      (1<<5)
#define BUTTON_PRE      (1<<7)

#define BUTTON_HW_INIT
#define BUTTON_HW_READ (255 - EXPANDER_Read())
#define BUTTON_MASK (BUTTON_LEFT | BUTTON_RIGHT | BUTTON_UP   | BUTTON_DOWN |\
                     BUTTON_SET  | BUTTON_OUT   | BUTTON_MODE | BUTTON_MEM)
#define BUTTON_VALUE (uint8_t)BUTTON_GetValue()

/**
 * Softpower pins PA1, PA2
 * 
 * PA1/ADC1 - Can measure voltage after DC jack
 * PA2 - Can detect if power key was pressed by reading ADC2.
 *       Seting this pin as digital output and writing low perform
 *       poweroff
 * */

#define PWR_BTN_PRESSED      0x300 // TODO: Fix voltage fluctuation on PA2 with different input voltages

#define PWR_BTN_PIN          PA_2

#define SOFT_POWER_OFF                     \
{                                          \
    pinWrite(PWR_BTN_PIN, GPIO_PIN_RESET); \
    pinInit(PWR_BTN_PIN, GPO_2MHZ);        \
    while(1);                              \
}

#define SPOWER_INIT                   \
{                                     \
    pinInit(PWR_BTN_PIN, GPI_ANALOG); \
}

#define GET_PWR_BTN         (ADC2_Read(ADC_PWR_SW_CH) > PWR_BTN_PRESSED)


/**
 * LEDS and debug pin
 * */
#define LED_PIN         PC_13
#define LED_INIT        pinInit(LED_PIN, GPO_2MHZ)
#define LED_TOGGLE      HAL_GPIO_TogglePin(PIN_NAME_TO_PORT(LED_PIN), PIN_NAME_TO_PIN(LED_PIN))
#define LED_OFF         pinWrite(LED_PIN, GPIO_PIN_SET)
#define LED_ON          pinWrite(LED_PIN, GPIO_PIN_RESET)

#define DBG_PIN         PB_6
#define DBG_PIN_INIT    pinInit(DBG_PIN, GPO_2MHZ);
#define DBG_PIN_HIGH    pinWrite(DBG_PIN, GPIO_PIN_SET)
#define DBG_PIN_LOW     pinWrite(DBG_PIN, GPIO_PIN_RESET)
#define DBG_PIN_TOGGLE  pinToggle(DBG_PIN)

#if defined(ENABLE_DEBUG)
    #define DBG_PRINT dbg_printf
    #define DBG_DUMP_LINE dbg_HexDumpLine
#else
    #define DBG_PRINT(...)
    #define DBG_DUMP_LINE(...)
#endif

/**
 * Output enable pin
 * */
#define PSU_OE_PIN      PB_1
#define PSU_OE_INIT     pinWrite(PSU_OE_PIN, GPIO_PIN_RESET); pinInit(PSU_OE_PIN, GPO_2MHZ)
#define PSU_OE_SET(_X)  pinWrite(PSU_OE_PIN, _X)

/**
 * Analog mux selectors
 * PA7-4
 * */
#define MUX_S0  PA_4
#define MUX_S1  PA_5
#define MUX_S2  PA_6
#define MUX_S3  PA_7

#define MUX_SEL_INIT \
{                                                                \
    pinWrite(MUX_S0, GPIO_PIN_RESET); pinInit(MUX_S0, GPO_2MHZ); \
    pinWrite(MUX_S1, GPIO_PIN_RESET); pinInit(MUX_S1, GPO_2MHZ); \
    pinWrite(MUX_S2, GPIO_PIN_RESET); pinInit(MUX_S2, GPO_2MHZ); \
    pinWrite(MUX_S3, GPIO_PIN_RESET); pinInit(MUX_S3, GPO_2MHZ); \
}

#define MUX_SELECT(CH) portWrite(PORTA, (portRead(PORTA) & ~(0xF<<4)) | (CH) << 4)

/**
 * Buzzer
 * */
#define BUZ_INIT

/**
 * Delay and tick count
 * */
#define GetTicks HAL_GetTick
#define DelayMs(d) HAL_Delay(d)

static inline uint32_t ElapsedTicks(uint32_t start_ticks){ 
    uint32_t current = GetTicks(); 
    //return (current > start_ticks) ? current - start_ticks : 0xFFFFFFFF - start_ticks + current;
    return current - start_ticks;
}

void TICK_Init(void);
/**
 * SPI
 * */
#define SPI_BLOCK_DMA

void SPI_Init(void);
uint8_t SPI_Send(uint8_t data);
void SPI_Read(uint8_t *dst, uint32_t len);
void SPI_WriteDMA(uint16_t *dst, uint32_t len);
/**
 * Display
 * PB3  -> BKL
 * PB12 -> CS
 * PB13 -> SCK
 * PB14 -> RS
 * PB15 -> SDO
 * */
#define TFT_W               80
#define TFT_H               160  // 162 on GRAM

#define TFT_OFFSET_SOURCE	26
#define TFT_OFFSET_GATE		1
#define TFT_BGR_FILTER

#define LCD_CD_Pin          GPIO_PIN_14
#define LCD_CD_GPIO_Port    GPIOB
#define LCD_BKL_Pin         GPIO_PIN_3
#define LCD_BKL_GPIO_Port   GPIOB
#define LCD_CS_Pin          GPIO_PIN_12
#define LCD_CS_GPIO_Port    GPIOB

#define LCD_CD0             LCD_CD_GPIO_Port->BRR = LCD_CD_Pin
#define LCD_CD1             LCD_CD_GPIO_Port->BSRR = LCD_CD_Pin
#define LCD_BKL0            LCD_BKL_GPIO_Port->BRR = LCD_BKL_Pin
#define LCD_BKL1            LCD_BKL_GPIO_Port->BSRR = LCD_BKL_Pin
#define LCD_CS0             LCD_CS_GPIO_Port->BRR = LCD_CS_Pin
#define LCD_CS1             LCD_CS_GPIO_Port->BSRR = LCD_CS_Pin
#define LCD_RST0
#define LCD_RST1

#define LCD_W LCD_GetWidth()
#define LCD_H LCD_GetHeight()

/** 
 * stdout
 * */
#if defined(ENABLE_USB_CDC) || defined(ENABLE_UART)
extern StdOut stdio_ops;
#define SERIAL_IO &stdio_ops
#elif defined(ENABLE_DEBUG)
extern stdout_t dummy_out;
#define SERIAL_IO &dummy_out
#endif


#if defined(ENABLE_USB_CDC)
void MX_USB_DEVICE_Init(void);
#elif defined(ENABLE_UART)
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

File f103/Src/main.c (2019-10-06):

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

/* Includes ------------------------------------------------------------------*/
#include "main.h"
#include "cmsis_os.h"
#include "usb_device.h"

/* USER CODE BEGIN Includes */
#include "board.h"
#include "usbd_cdc_if.h"
/* USER CODE END Includes */

ADC_HandleTypeDef hadc1;

I2C_HandleTypeDef hi2c2;

osThreadId defaultTaskHandle;
/* USER CODE BEGIN PV */
extern uint32_t g_pfnVectors;
/* USER CODE END PV */

void SystemClock_Config(void);
static void MX_GPIO_Init(void);
static void MX_I2C2_Init(void);
static void MX_ADC1_Init(void);
void StartDefaultTask(void const * argument);

/* USER CODE BEGIN PFP */
void psu(void);

/* USER CODE END PFP */

/**
  * @brief  The application entry point.
  * @retval int
  */
int main(void)
{
  /* USER CODE BEGIN 1 */
	/* 
		PB10 -> SCL (LCD_CD)
		PB11 -> SDA (LCD_LED)
    */ 
  
  /* Vector Table Relocation to startup vector table  */
  SCB->VTOR = (uint32_t)(&g_pfnVectors) & 0xFFFF;
  reenumerate_usb();
  /* USER CODE END 1 */
  

  /* MCU Configuration--------------------------------------------------------*/

  /* Reset of all peripherals, Initializes the Flash interface and the Systick. */
  HAL_Init();

  /* Configure the system clock */
  SystemClock_Config();

  /* Initialize all configured peripherals */
  MX_GPIO_Init();
  MX_I2C2_Init();
  MX_ADC1_Init();
  /* USER CODE BEGIN RTOS_MUTEX */
  /* add mutexes, ... */
  /* USER CODE END RTOS_MUTEX */

  /* USER CODE BEGIN RTOS_SEMAPHORES */
  /* add semaphores, ... */
  /* USER CODE END RTOS_SEMAPHORES */

  /* USER CODE BEGIN RTOS_TIMERS */
  /* start timers, add new ones, ... */
  /* USER CODE END RTOS_TIMERS */

  /* USER CODE BEGIN RTOS_QUEUES */
  /* add queues, ... */
  /* USER CODE END RTOS_QUEUES */

  /* Create the thread(s) */
  /* definition and creation of defaultTask */
  osThreadDef(defaultTask, StartDefaultTask, osPriorityNormal, 0, 128);
  defaultTaskHandle = osThreadCreate(osThread(defaultTask), NULL);

  /* USER CODE BEGIN RTOS_THREADS */
  /* add threads, ... */
  /* USER CODE END RTOS_THREADS */

  /* Start scheduler */
  osKernelStart();
  
  /* We should never get here as control is now taken by the scheduler */

  /* Infinite loop */
  /* USER CODE BEGIN WHILE */
  while (1)
  {   

    /* USER CODE END WHILE */

    /* USER CODE BEGIN 3 */
  }
  /* USER CODE END 3 */
}

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
/* USER CODE BEGIN Header_StartDefaultTask */
/**
  * @brief  Function implementing the defaultTask thread.
  * @param  argument: Not used 
  * @retval None
  */
/* USER CODE END Header_StartDefaultTask */
void StartDefaultTask(void const * argument)
{
    
    
                 
  /* init code for USB_DEVICE */
  MX_USB_DEVICE_Init();

  /* USER CODE BEGIN 5 */
  /* Infinite loop */
    psu();
    vTaskDelete( NULL );
  /* USER CODE END 5 */ 
}

/**
  * @brief  Period elapsed callback in non blocking mode
  * @note   This function is called  when TIM4 interrupt took place, inside
  * HAL_TIM_IRQHandler(). It makes a direct call to HAL_IncTick() to increment
  * a global variable "uwTick" used as application time base.
  * @param  htim : TIM handle
  * @retval None
  */
void HAL_TIM_PeriodElapsedCallback(TIM_HandleTypeDef *htim)
{
  if (htim->Instance == TIM4) {
    HAL_IncTick();
  }
}

/**
  * @brief  This function is executed in case of error occurrence.
  * @retval None
  */
void Error_Handler(void)
{
  /* USER CODE BEGIN Error_Handler_Debug */
  /* User can add his own implementation to report the HAL error return state */
  while(1)
  {
  }
  /* USER CODE END Error_Handler_Debug */
}

#ifdef  USE_FULL_ASSERT
/**
  * @brief  Reports the name of the source file and the source line number
  *         where the assert_param error has occurred.
  * @param  file: pointer to the source file name
  * @param  line: assert_param error line source number
  * @retval None
  */
void assert_failed(uint8_t *file, uint32_t line)
{ 
  /* USER CODE BEGIN 6 */
  /* User can add his own implementation to report the file name and line number,
     tex: printf("Wrong parameters value: file %s on line %d\r\n", file, line) */
  /* USER CODE END 6 */
}
#endif /* USE_FULL_ASSERT */

/************************ (C) COPYRIGHT STMicroelectronics *****END OF FILE****/

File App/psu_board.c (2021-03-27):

#include "board.h"
#include "FreeRTOS.h"
#include "queue.h"
#include "task.h"
#include "usbd_cdc_if.h"
#include <stdout.h>

#if defined(ENABLE_I2C)
static I2C_HandleTypeDef hi2c2;
#endif

void BOARD_Init(void){
    
    RCC->APB2ENR |= RCC_APB2ENR_IOPAEN | RCC_APB2ENR_IOPBEN | RCC_APB2ENR_IOPCEN;
    
    LED_INIT;
    PSU_OE_INIT;
    MUX_SEL_INIT;
    SPOWER_INIT;
    DBG_PIN_INIT;
        
    SPI_Init();
#if defined(ENABLE_I2C)
    I2C_Init();
#endif
    RTC_Init();
}

/**
 * @brief Time base configuration.
 * SysTick is assigned to FreeRTOS, 
 * Timer 4 is used to generate a 1ms time base instead
 * */
void TICK_Init(void){

    RCC->APB1ENR  |= RCC_APB1ENR_TIM4EN;
    RCC->APB1RSTR |= RCC_APB1ENR_TIM4EN;
    RCC->APB1RSTR &= ~RCC_APB1ENR_TIM4EN;

    TIM4->PSC = (uint32_t)((SystemCoreClock / 1000000UL) - 1);
    TIM4->ARR = 1000 - 1;
    TIM4->DIER |= TIM_DIER_UIE;

    HAL_NVIC_SetPriority(TIM4_IRQn, 0 ,0);
    HAL_NVIC_EnableIRQ(TIM4_IRQn);
    TIM4->CR1 = TIM_CR1_CEN;
}

void TIM4_IRQHandler(void){
    TIM4->SR = ~TIM_IT_UPDATE;
    HAL_IncTick();
}

/**
 * PWM Driver
 * 
 * PWM1 - PB4
 * PWM2 - PB5
 * PWM3 - PB0
 * 
 * \param initial - startup duty for each channel
 * 
 * */
void PWM_Init(uint16_t pwm1, uint16_t pwm2, uint16_t pwm3){

     /* Configure Timer 3 */
    RCC->APB1ENR  |= RCC_APB1ENR_TIM3EN;
    RCC->APB1RSTR |= RCC_APB1ENR_TIM3EN;
    RCC->APB1RSTR &= ~RCC_APB1ENR_TIM3EN;

    TIM3->CR1 = TIM_CR1_ARPE;
    TIM3->CCMR1 = (6<<TIM_CCMR1_OC2M_Pos) | (6<<TIM_CCMR1_OC1M_Pos) | (TIM_CCMR1_OC2PE) | (TIM_CCMR1_OC1PE);  // PWM Mode 1
    TIM3->CCMR2 = (6<<TIM_CCMR2_OC3M_Pos) | (TIM_CCMR2_OC3PE); 
    TIM3->CCER = TIM_CCER_CC3E | TIM_CCER_CC2E | TIM_CCER_CC1E;
    TIM3->PSC = 1; // Timer3 freq = SystemClock / 2

    TIM3->ARR = PWM_MAX_VALUE - 1;
    TIM3->CCR1 = pwm1;
    TIM3->CCR2 = pwm2;
    TIM3->CCR3 = pwm3;
    
    TIM3->CR1 |= TIM_CR1_CEN;     // Start pwm before enable outputs

    /* Configure PWM pins */
    GPIOB->CRL &= ~(0xFF000F << 0); // PB5-PB4, PB0
    GPIOB->CRL |= (0xAA000A << 0);
    // remap PB5-PB4
    AFIO->MAPR |= (2 << 10);    
}

/**
 * Set new pwm value for the given channel
 * \param ch        channel to be updated 0-3
 * \param newvalue  New pwm value
 * */
void PWM_Set(uint8_t ch, uint16_t newvalue){

    if(newvalue >  PWM_MAX_VALUE || newvalue < PWM_MIN_VALUE)    
        return;

    ((uint32_t*)&TIM3->CCR1)[ch & 3] = newvalue;
}

uint16_t PWM_Get(uint8_t ch){
    uint32_t *ccr = (uint32_t*)&TIM3->CCR1;     
    return ccr[ch&3];
}

/**
 * Console stdout, stdin
 * */
#if defined(ENABLE_CLI)
#define STDIN_QUEUE_LENGTH 128
#define STDOUT_QUEUE_LENGTH 128
#define STDIO_QUEUE_ITEM_SIZE 1

static QueueHandle_t stdin_queue;
static QueueHandle_t stdout_queue;

// called from ISR
void stdin_queue_char(uint8_t *c){
    xQueueSendToBackFromISR(stdin_queue, c, NULL);
}

static uint8_t stdin_try_dequeue(char *c){
    if(stdin_queue == NULL)
        return 0;
    return xQueueReceive(stdin_queue, c, 0) == pdPASS;
}

static char stdin_wait_char(void){
    char c;
    xQueueReceive(stdin_queue, &c, portMAX_DELAY);
    return c;
}

uint8_t stdin_queued(void){
    return STDIN_QUEUE_LENGTH - uxQueueSpacesAvailable(stdin_queue);
}

static void stdio_init(void){
    stdin_queue = xQueueCreate( STDIN_QUEUE_LENGTH, STDIO_QUEUE_ITEM_SIZE );
    configASSERT( stdin_queue != NULL );

    stdout_queue = xQueueCreate( STDIN_QUEUE_LENGTH, STDIO_QUEUE_ITEM_SIZE );
    configASSERT( stdout_queue != NULL );

    #if defined(ENABLE_USB_CDC)
    MX_USB_DEVICE_Init();
    #elif defined(ENABLE_UART)
    UART_Init();
    #endif
}
#endif

#ifdef ENABLE_USB_CDC
static void putAndRetry(uint8_t *data, uint16_t len){
uint32_t retries = 1000;
	while(retries--){
		if(	CDC_Transmit_FS(data, len) == USBD_OK)
			break;
	}
}

static void stdout_enqueue_char(char c){
	putAndRetry((uint8_t*)&c, 1);
}

static void stdout_puts(const char *s){
uint16_t len = 0;
	
	while( *((const char*)(s + len)) != '\0'){
		len++;	
	}
	putAndRetry((uint8_t*)s, len);
}
#endif

#if defined(ENABLE_UART)
void UART_Init(void){
    RCC->APB2ENR |= RCC_APB2ENR_USART1EN;
    RCC->APB2RSTR |= RCC_APB2RSTR_USART1RST;
    RCC->APB2RSTR &= ~RCC_APB2RSTR_USART1RST;

    pinInit(UART_TX_PIN, GPO_AF | GPO_2MHZ);  // TX
    pinInit(UART_RX_PIN, GPI_PU);            // RX

    USART1->BRR = 0x271;        //115200
    USART1->CR1 = USART_CR1_RXNEIE | USART_CR1_TE | USART_CR1_RE | USART_CR1_UE;

    //USART1->CR1 |= USART_CR1_UE;
    //while((USART1->SR & USART_SR_TC) == 0);
    //NVIC_PriorityGroupConfig( NVIC_PriorityGroup_4 );  
    HAL_NVIC_SetPriority(USART1_IRQn, IRQ_PRIORITY_LOW ,0);
    NVIC_EnableIRQ(USART1_IRQn);
}

static void stdout_enqueue_char(char c){
    xQueueSendToBack(stdout_queue, &c, pdMS_TO_TICKS(100));
    USART1->CR1 |= USART_CR1_TXEIE;
}

static void stdout_puts(const char *s){
    while(*s){
        xQueueSendToBack(stdout_queue, s++, pdMS_TO_TICKS(100));
    }
    USART1->CR1 |= USART_CR1_TXEIE;
}
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

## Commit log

2015-06-10 move to git
    [linear_lm358.brd, linear_lm358.sch]
2016-08-28 Added Rtc changes on gui
    Added timer support for load, gui lay out now is the same for PSU and Load, abandoned graphic idea due to display limitations
2018-11-10 Commited undocumented lastest changes
    [linear_lm358.brd, linear_lm358.sch]
2018-11-10 Added folder for v2.0
    [linear_lm358.brd, linear_lm358.sch]
2018-11-10 Moved v2.0 to pic folder
    [linear_lm358.brd, linear_lm358.sch]
2018-11-10 Added Android app
    [decode.xlsx]
2018-11-17 Addec ADC command, made console non blocking
2018-11-18 ADD: Timer, ADC, buttons and board.h
2018-11-20 ADD: ADC configuration
2019-01-05 ADD: psu v3 specific adc driver
2019-01-05 UPD: ADC command for new adc driver
2019-01-05 ADD: pwm driver files
2019-01-06 CHG: ADC Trigger timer to TIM2_CC2 Event
2019-01-06 WIP: pwm
2019-01-06 IMP: PWM api
2019-01-06 ADD: command pwm
2019-09-23 Fixed no image after power cycle
    [board.h]
2019-09-24 Add power down command, remove direct calls to I2C driver from lcd driver
2019-10-02 Normalize all the line endings
    [linear_lm358.brd, linear_lm358.sch]
2019-10-02 WIP: Debug usb not working
    [psu_main.cpp]
2019-10-02 FIX: virtual com not starting
    [board.h, main.c]
2019-10-04 Replaced fifo with queue on vcp
    [psu_main.cpp]
2019-10-04 Added DMA to i2c
2019-10-05 Changed debug pin to PA4
2019-10-06 working i2c with dma
2019-10-06 Moved DMA code to board.c, check end of transfer flag on DMA interrupt
2019-10-06 Updated button symbols
2019-10-07 Added base screens for operating modes and symbol for dma select
2019-10-09 add i2c io expander driver
2019-10-09 current set through keypad
2019-10-12 Added comment on pwm
2019-10-12 new symbols for pwm
2019-10-12 fix missing last byte on DMA transfers
2019-10-12 Fix out icon disapear on mode change
    [psu_main.cpp]
2019-10-19 FIX: adc working with four channels in dual mode
    [board.h, psu.h, psu_main.cpp]
2019-10-19 UPD: debug led macro
2019-10-26 change debug led macros
2019-10-26 REM: text print formated feature
2019-10-26 ADD: calibration data structure
2019-10-26 IMP: output power update
2019-10-26 ADD: dedicated print functions for power and voltage
2019-10-26 ADD: charger mode
2019-10-27 ADD: Icon for charger, renamed field on state
2019-10-27 CHG: remapped PWM and ADC pins
2019-10-27 ADD: current print function
2019-10-27 IMP: charger mode ui
2019-11-03 Fix: IO expander init
    [psu_main.cpp]
2019-11-03 UPD: cmd pwm Help
2020-05-20 Change to 80x160 TFT display
    OLED display was better option for laser4+ project
2020-05-20 Changed project folder structure and removed unused code
    [decode.xlsx, linear_lm358.brd, linear_lm358.sch]
2020-05-20 Moved I2C initialization to board file.
2020-05-23 Fix bug on dma transfers
    [psu_board.c]
2020-05-23 Add 'v' option to pwm command
2020-05-23 Added dual buffer for DMA
2020-06-07 UPD: pwm command
    Now the duty can be set in a single command
2020-06-08 ADD: Adc muc component
2020-06-08 Use adc mux
2020-06-13 Associate color to trace number
2020-06-14 ADD: ADC startup calibration
2020-06-22 wip: adc command
2020-06-27 UPD: pwm range value and help
2020-06-28 Change to adc manager Use pin name
2020-06-28 FIX: pwm startup values
    [psu.h, psu_main.cpp]
2020-07-26 IMP: Serial communication with HW uart
2020-08-05 REM: Startup values for PWM, load default values from eeprom
2020-08-05 ADD: missing changes, comments
    [adcmgr.c]
2020-08-05 ADD: print all channels values Stop adc manager conversions
2020-08-05 ADD: print pwm values
2020-08-06 CHG: _scratch buffer to static FIX: 8bit inversion on button read
    [board.h, psu_board.c]
2020-08-06 CHG: Reset graph data in init FIX: print out of bound data
2020-08-07 Filter valid data to be displayed
2020-08-07 ADD: print presetindex
2020-08-07 Early uart init
2020-08-07 FIX: discard set mode when screen is changed
    [psu.h]
2020-08-14 WIP: screen load, print measurements
2020-10-27 CHG: Use uint32_t insted of float for sotring set values
    Move print functions to base class
2020-10-27 Change pin masks to match HW
    Added macros to control HW
2020-10-27 MOV: ADC conversion sequence to adcmgr
2020-10-29 IMP: I2C EEPROM REM: NVDATA
2020-10-31 Added option to break adc manager call loop.
    Implemented cmdadc mgr parameter functions
2020-10-31 CHG: presets, pwm calibration and an channel gains placed on ram
    This change allows loading default values or from EEPROM, this now allows
    erase/set eeprom with default values
2020-10-31 FIX: preset values update
    [psu_main.cpp]
2020-11-01 Access control to I2C peripheral
2020-11-03 Display USB current and input voltage on status cmd
2020-11-05 CHG: PWM start up values
2020-11-05 IMP: get load voltage and current
2020-11-05 IMP: soft power key
2020-11-21 UPD: Backligth pin
2020-11-22 ADD: toggle function for output enable
    Memory allocation fail hook
    [psu.h, psu_main.cpp]
2020-11-29 Revert to NPN transistor on softpower
    [board.h, psu_main.cpp]
2020-11-29 Thread safe call
2020-11-29 Added empty classes for load and charger screens
2020-12-05 getter for battery pack cell voltage
2020-12-05 IMP: charger screen
2020-12-06 Added preset for charging
2020-12-06 wip charge screen
2020-12-10 Added filter
2020-12-10 wip screen charger
2020-12-11 REM unused code, implemented set/get adc channle gain
2020-12-11 REM unused code, implemented set/get adc channels gain
2020-12-15 IMP: CLI pwm configuration
2020-12-15 CHG: battery voltage set from pre defined values
2020-12-23 IMP: Charger charge capacity
2020-12-27 Reset capacity with PRE key
2021-03-06 CHG: Return accumulated capacity
    Accumulated capacity is computed using parameter insted global variable
2021-03-07 Implemented constant current, end voltage edit, capacity and time reset with Preset button
2021-03-13 Added buitext for usb current
2021-03-13 CHG: To timed ADC, improove digital filtering
2021-03-20 Refcator: Replaced magic numbers
    [cmdadc.cpp]
2021-03-27 Filter opamp dead band

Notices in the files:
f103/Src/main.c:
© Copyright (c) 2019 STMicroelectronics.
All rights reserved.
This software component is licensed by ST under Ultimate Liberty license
